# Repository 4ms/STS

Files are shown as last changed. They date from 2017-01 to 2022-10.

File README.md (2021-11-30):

# STS
## Stereo Triggered Sampler

Firmware for the Stereo Triggered Sampler, from 4ms Company.

The hardware contains:

*	180MHz 32-bit ARM chip with FPU (STM32F427)
*	Two Stereo codec chips, very low noise and low jitter (CS4721)
	*	Total of four audio inputs and four audio outputs
*	Eight potentiometers
*	Six Analogue inputs:
	*	Four unipolar analogue inputs (0 to 5V)
	*	Two bipolar analogue inputs (-5V to 5V)
*	Five LED buttons (momentary)
*	Two three-position switches
*	Five trigger/gate digital inputs
*	Three digital outputs
*	Two LEDs, capable of being dimmed with PWM
*	Separate analogue power supplies for each codec, and also the ADC 
*	Efficient 3.3V DC-DC converter accepts a wide range of input voltages

## Setting up your environment
You need to install the GCC ARM toolchain.
This project is known to compile with arm-none-eabi-gcc version 7.3.1, version 8.2.1, version 9.2.1, version 10.2.1, and 10.3.1. It's likely to compile with other versions as well.

It's recommended (but not necessary) to install ST-UTIL/stlink. Without it, you will have to update using the audio bootloader, which is very slow (5 minutes per update).
With ST-UTIL or stlink and a programmer, you can update in 5-20 seconds.
The Texane stlink package contains a gdb debugger, which works with ST-LINK programmers such as the [STM32 Discovery boards](http://www.mouser.com/ProductDetail/STMicroelectronics/STM32F4DISCOVERY/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) to connect to the Spectral's 4-pin SWD header. The STM32F4 Discovery Board is low-cost (under US$15) and works great as a programmer and debugger.

You also may wish to install an IDE such as Eclipse. There are many resources online for setting up GCC ARM with Eclipse (as well as commerical software). This is totally optional. Instead of an IDE you can use your favorite text editor and a few commands on the command line (Terminal) which are given below.

Continue below for Max OSX, Linux, or Windows instructions.

### Mac OSX

For Mac OSX, follow these instructions to install brew and then the arm toolchain and st-link (taken from https://github.com/nitsky/homebrew-stm32):

	ruby -e "$(curl -fsSL https://raw.githubusercontent.com/Homebrew/install/master/install)"
	brew tap nitsky/stm32
	brew install arm-none-eabi-gcc
	brew install stlink
	
Unfortunately `brew install arm-none-eabi-gcc` will download an old version of arm-none-eabi-gcc. This will work fine, so you can stop here if you want to do the easiest thing possible. But if you want to develop new firmware using C++17 or C++20 features, you'll need a newer toolchain. You can get a later version of arm-none-eabi-gcc [from ARM's website here](https://developer.arm.com/tools-and-software/open-source-software/developer-tools/gnu-toolchain/gnu-rm/downloads). After you unzip the download, add the `bin/` directory to your `PATH` like this:

	export PATH=$PATH:(path to the unzipped gcc-arm-none-eabi folder)/bin

Alternatively, if you don't want to mess with your PATH, you can export an environment variable that the Makefile will look for, like this (note the trailing slash):

	export TOOLCHAIN_DIR=(path to the unzipped gcc-arm-none-eabi folder)/bin/

That's it! Continue below to **Clone the Projects**

### Linux

For linux, check your package manager to see if there is a package for arm-none-eabi-gcc or gcc-arm-embedded or gcc-arm-none-eabi. Or just download it here:

[Download GCC ARM toolchain](https://developer.arm.com/tools-and-software/open-source-software/developer-tools/gnu-toolchain/gnu-rm/downloads)

Next, install st-link from texane:

	sudo apt-get install git libusb-1.0.0-dev pkg-config autotools-dev
	cd (your work directory)
	git clone https://github.com/texane/stlink.git
	cd stlink
	./autogen.sh
	./configure
	make
	export PATH=$PATH:(your work directory)/stlink

The last command makes sure that the binary st-flash is in your PATH so that the Makefile can run it to program your module. Alternatively you can omit the last command and run this instead:

	export TOOLCHAIN_DIR=(path to the unzipped gcc-arm-none-eabi folder)/bin/

The above environment variable will be used by the STS's Makefile to find the compiler.
 
That's it! Continue below to **Clone the Projects**

### Windows
[Download GCC ARM toolchain](https://developer.arm.com/tools-and-software/open-source-software/developer-tools/gnu-toolchain/gnu-rm/downloads)

[Download ST-UTIL](http://www.st.com/web/en/catalog/tools/PF258168)

Install both. Please contact me if you run into problems that you can't google your way out of! 

## Clone the Projects

Make sure git is installed on your system. (OSX: type `brew install git` into the Terminal)

Create a work directory, and enter it.

Clone this project (STS) and the required submodule (which is libhwtest)

	git clone https://github.com/4ms/STS.git
	cd STS
	git submodule update --init
	
If you don't need to change the bootloader firmware or generate a .wav file for updating firmware, then you can skip to **Compiling**.

Otherwise, if you want to modify the audio bootloader firmware, or create .wav files for sharing your custom firmware with others, then clone these projects as well:

	cd ..         ## if you were in the STS dir, go up one level
	git clone https://github.com/4ms/sts-bootloader.git  
	git clone https://github.com/4ms/stmlib.git
	git clone https://github.com/4ms/stm-audio-bootloader.git
	
Create a symlink for stm-audio-bootloader so that it works with python (required to generate the .wav file for audio bootloading)

     ln -s stm-audio-bootloader stm_audio_bootloader

Verify that your directories are as follows:

	(work directory)
	|  
	|--STS/  
	|--sts-bootloader/  
	|--stm-audio-bootloader/  
	|--stm_audio_bootloader/   <----symlink to stm-audio-bootloader
	|--stmlib/

## Compiling
Make your changes to the code in the STS directory. When ready to compile, build the project like this (make sure you're in the `STS/` directory)

	make

This creates an main.elf, main.bin, and main.hex file in the build/ directory.

## Programmer (Hardware) ##

Once you compile your firmware, you need to flash it to your STS. You will need a hardware device that connects to your computer's USB port. The other side of the programmer has a header that connects to the STS's 4-pin SWD header.

You have several options:

### Option 1) ST-LINKv2 programmer ###

The [ST-LINK v2 from ST corporation](http://www.mouser.com/search/ProductDetail.aspx?R=0virtualkey0virtualkeyST-LINK-V2) is the offical programmer from ST. The ST-LINK v2 has a 20-pin JTAG header, and you need to connect four of these to your STS. More details on this are below.

The ST-LINKv2 programmer can be used with ST-LINK software for Mac, Linux, or Windows; or ST-UTIL software for Windows; or STM32CubeProgrammer software for any platform. 

### Option 2) Discovery board programmer ###

The [STM32 Discovery boards](http://www.mouser.com/search/ProductDetail.aspx?R=0virtualkey0virtualkeySTM32F407G-DISC1) are low-cost (around US$25) and work great as a programmer and debugger. The 'Disco' board is essentially an ST-LINKv2, plus some extra stuff. While the ST-LINK v2 is encased in a plastic enclosure, the Discovery board is open and could potentially be damaged if you're not careful. Read the Discovery board's manual to learn about setting the jumpers to use it as an SWD programmer (rather than an evaluation board). ST makes many variations of the Discovery board, and to my knowledge they all contain an ST-LINK programmer.

The Discovery board programmer is essentially an ST-LINKv2, so it can be used with all the same software that the ST-LINKv2 can (see above section).

### Option 3) SEGGER's J-Link or J-Trace ###

Another option is [SEGGER's J-link programmer](https://www.segger.com/jlink-debug-probes.html). There is an educational version which is very affordable and a good choice for a programmer if you meet the requirements for educational use. There are various professional commercial versions with a number of useful features. The J-link uses SEGGER's propriety software, Ozone, which not only will flash a hex or bin file, but can be used as a powerful GUI debugger if you use it to open the .elf file. There also are command-line commands for flashing.
J-Link software runs on Mac, Linux, and Windows and is free of cost.

### Option 4) Audio Bootloader ###

The STS has an audio bootloader built-in, so you can just compile your project using `make wav` and then play the wav file into the audio input of the STS while in bootloader mode (see STS User Manual for detailed procedure). No additional hardware or software is necessary.

This works well and is the safest option. However it's very slow (up to 5 minutes per update). If you are going to be making a series of changes, this will be a very slow process! However if you want to share your custom firmware with others, it's a great way to package it since users don't need any special devices to update.

When ready to build an audio file for the bootloader, make it like this:

	make wav

This requires python to run. It creates the file `main.wav` in the `build/` directory. Play the file from a computer or device into the STS by following the instructions in the User Manual on the [4ms STS page](http://4mscompany.com/STS). 

## Programmer (Software)

Depending on the hardware you chose, one or more of the following software options will work:

### ST-LINK ###

This software works with the ST-LINK v2 and the Discovery board to flash your STS.

__MacOS:__

```
brew install stlink
```

__Linux:__

Use your package manager to install `stlink-tools`. See [stlink README](https://github.com/stlink-org/stlink) for direct links.

__Windows:__

Download the [latest binary (v1.3.0)](https://github.com/stlink-org/stlink/releases/download/v1.3.0/stlink-1.3.0-win64.zip). If that link doesn't work anymore, or you want to try a newer version, go to [stlink-org/stlink github page](https://github.com/stlink-org/stlink).

__Programming using st-link__

You can flash the compiled .bin file by typing either

	st-flash write build/main.bin 0x08008000

or the shortcut:

	make stflash
	
This writes the main.bin file starting at the 0x08008000 sector, which is the first sector of the application code.

__Debugging__

The gcc-arm toolchain includes a gdb debugger, but you'll need a server to use it. The st-link software includes st-util which will provide this. OpenOCD and J-link are two other options. Configuring debugging is beyond the scope of this README, but there are plenty of tutorials online. See the [stlink README](https://github.com/stlink-org/stlink) for a quick start.

### J-Link/Ozone ###

If you're using a J-Link or J-Trace hardware programmer to flash your STS, download and install [Ozone](https://www.segger.com/downloads/jlink). Ozone is a GUI debugger which can program, too. For command-line options, consider [J-Link Software and Documentation Pack](https://www.segger.com/j-link-software.html), which contains the GDB server and other tools.

To program your STS, open Ozone and then use the Project Wizard to create a new project. Select the STM32F427ZG for the chip. Use the default settings elsewhere. On the page that lets you select a file, select the main.elf file that you compiled. You can then save this project. To program, just click the green power/arrow symbol at the upper left.

You also can use the CLI tools to flash the hex/elf file, see J-Link documentation for details. The Makefile contains a shortcut for this:

	make flash

J-Link and Ozone is available for Mac, Windows, and Linux.

### STM32CubeProgrammer ###

The STM32CubeProgrammer is ST's official programaming software available for all platforms. [You can find it here](https://www.st.com/en/development-tools/stm32cubeprog.html)

Documentation is included with the download.

### ST-UTIL (Windows only) ###

ST-UTIL is a program from ST that runs on Windows only. You can find it on [ST.com](https://my.st.com/content/my_st_com/en/products/development-tools/software-development-tools/stm32-software-development-tools/stm32-programmers/stsw-link004.html)

It works with the ST-LINKv2 and Discovery boards.

## Connecting the programmer to the STS ##

**Discovery Board**: The Discovery board has a 6-pin SWD header, and you can connect that pin-for-pin to the first 4 pins on the STS's SWD header. You can use a 0.1" spaced 4-pin Jumper Wire such as [this one from Sparkfun](https://www.sparkfun.com/products/10364). Pay attention to Pin 1 (marked by "1" on the STS board), or you risk damaging the ARM chip.

**ST-LINK v2 or SEGGER J-Link**: Both the ST-LINK and the SEGGER J-link have a 20-pin JTAG connector. You need to connect 4 of these pins to the STS's 4-pin SWD connector, using 4 wires: [here's a pack of 10](https://www.sparkfun.com/products/8430). Pay attention to Pin 1 (marked by "1" on the STS board), or you risk damaging the ARM chip.
 
Look at these images:
 
  * JTAG: [20-pin pinout](http://www.jtagtest.com/pinouts/arm20)
  * SWD: [6-pin pinout](https://wiki.paparazziuav.org/wiki/File:Swd_header_discovery_board.png)
  * JTAG-to-SWD: [JTAG-to-SWD-pinout](https://4mscompany.com/JTAG-to-SWD-pinout.png). 

Then use your jumper wires to connect:
 
  * SWD pin 1 (VDD) -> JTAG pin 1 (VREF)
  * SWD pin 2 (SWCLK) -> JTAG pin 9 (TCK)
  * SWD pin 3 (GND) -> JTAG pin 4 (GND)
  * SWD pin 4 (SWDIO) -> JTAG pin 7 (TMS)

Here's more info in case you want it explained in another way:

  * [This image](https://www.alexwhittemore.com/wp-content/uploads/2014/08/schematic.jpg) draws this out. (Taken from [this post](https://www.alexwhittemore.com/st-linkv2-swd-jtag-adapter/))
  * [ST's manual](http://www.st.com/content/ccc/resource/technical/document/user_manual/70/fe/4a/3f/e7/e1/4f/7d/DM00039084.pdf/files/DM00039084.pdf/jcr:content/translations/en.DM00039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)
  * [How to make an adaptor](http://gnuarmeclipse.github.io/developer/j-link-stm32-boards/#the-st-6-pin-swd-connector)
  * Make your own adaptor from these gerber files: [JTAG-SWD-adaptor](https://github.com/4ms/pcb-JTAG-SWD-adaptor).

### Troubleshooting: ###

If you have trouble getting python to create a wav file, such as this error:

	ImportError: No module named stm_audio_bootloader

Then try this command:
	
	export PYTHONPATH=$PYTHONPATH:'.'

## Bootloader
The bootloader is a [separate project](https://github.com/4ms/stm-audio-bootloader), slightly modifed from the stm-audio-bootloader from [pichenettes](https://github.com/pichenettes/eurorack). 

The bootloader is already installed on all factory-built STS units.

## License
The code (software) is licensed by the MIT license.

The hardware is licensed by the [CC BY-NC-SA license](https://creativecommons.org/licenses/by-nc-sa/4.0/) (Creative Commons, Attribution, NonCommercial, ShareAlike).

See LICENSE file.

I would like to see others build and modify the STS and STS-influenced works, in a non-commercial manner. My intent is not to limit the educational use nor to prevent people buying hardware components/PCBs collectively in a group. If you have any questions regarding the license or appropriate use, please do not hesitate to contact me! 

## Guidelines for derivative works

Do not include the text "4ms" or "4ms Company" or the graphic 4ms logo on any derivative works. This includes faceplates, enclosures, or front-panels. It's OK (but not required) to include the text "Stereo Triggered Sampler" or "STS" if you wish.

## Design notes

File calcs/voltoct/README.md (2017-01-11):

Calculates volt/oct coefficients for Stereo Triggered Sampler
How to Use: Run ./mk
That's all. The output will be stored in voltoct.h, so move that to your project if you like.

If you want to see the output, run ./calc-voltoct

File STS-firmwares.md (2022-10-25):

# Stereo Triggered Sampler - Firmwares #
### How do I know what version I have? ###
Using a computer:

  * Put your microSD card into your computer. Open up the `__Sample List__.html` file. At the top it will say "Firmware version XXX".

Without a computer:

  1) Go into System Mode (_hold both Reverse, both Play, REC and REC Bank buttons down for a few seconds_). 

  2) Press and hold the Edit button. Look at the colors of Reverse buttons:

*  Left Reverse = __White__, Right Reverse = __Green__ ==> 1.5.x (latest version)
*  Left Reverse = __White__, Right Reverse = __Yellow__ ==> 1.4 
*  Left Reverse = __White__, Right Reverse = __Orange__ ==> 1.3
*  Left Reverse = __White__, Right Reverse = __Red__ ==> 1.2 
*  Left Reverse = __Orange__, Right Reverse = __Orange__ ==> 1.0 or 1.1 (see note below)

<!--
*Key: The left Reverse button shows the Major version number, and the right Reverse button shows the Minor version number. Off = 0, White = 1, Red = 2, Orange = 3, Yellow = 4, Green = 5, Cyan = 6, Blue = 7, Magenta = 8, Lavender = 9* -->

3) If the Reverse buttons stay Orange, then you have v1.0 or 1.1. To tell the difference between v1.0 and v1.1, press and hold just the left Reverse button in System Mode. If both Reverse buttons turn White, then you have v1.1. If they remain Orange, you have v1.0.

### Change log: ###

----
### v1.5.2b ###

*__Released:__* October 14, 2022

*__Download:__* [Firmware v1.5.2b](https://4mscompany.com/media/STS/firmware/STS-firmware-v1.5.2b.wav)

*__Improvements:__*

*__Bug Fixes:__*

   * __Start Pos would not go back to 0__: With longer sample files, adjusting Start Pos up and then back to 0 would sometimes set the start position such that the first few milliseconds of audio were truncated. Fixed.

   * __Clicking when re-triggering a sample with long Fade settings__: With longer Fade Up/Down Envelope times, re-triggering an already playing sample would prioritize low latency over the fade-down envelope, causing a click. In v1.5.2b the fade-down envelope is accelerated, adding a little bit of latency when re-triggering but removing the click. Setting the Fade Up/Down envelope time to fast removes the latency and clicking.

   * __Looping broken for very short samples when Perc Env is off__: When Percussive Envelope was turned off, setting the sample length to be very short could make it not loop. Bug introduced in 1.5.2. Fixed.

----
### v1.5.2 ###

*__Released:__* October 8, 2022

*__Improvements:__*

  * __Smaller firmware update files__: The size of the firmware file has been reduced, making the firmware update .wav file smaller by about 57% (from 5:55 to 3:22).

*__Bug Fixes:__*

   * __Long Fade In/Out Envelope times caused clicking in audio under certain circumstances__: When the Fade In/Out Envelope Time was set longer than the Trigger Delay Time, firing a play trigger into a channel that's already playing audio would cause the audio to re-start before the fade out had completed, causing a pop or click in the audio. Another circumstance was if the Fade In/Out Envelope Time or Percussive Envelope Time was set longer than time between Start Pos and the actual start of sample data, playing a sample in reverse would result in extra silence or glitchy audio. Bug appeared in v1.5, fixed in v1.5.2.

   * __Recording Sample Rate not presevered across reboots__: The Recording Sample Rate can be set in System Mode up to 96kHz. However, the next time the STS started up, the rate would be set back to 44.1kHz, yet the System Mode lights would indicate it was still in 96kHz. One symptom was that samples would play back at the wrong pitch. Bug fixed in v1.5.2.

----

### v1.5.1b ###

*__Released:__* June 28, 2022

*__New Features:__*

  * __Force Reload SD Card__: Hold down four buttons: Bank 1, Bank 2, Rec Bank and Rec, for about 2 seconds. Release the buttons when the startup sequence of lights displays.

*__Bug Fix:__*

   * __Unrelated sample file played in certain circumstances__: When Start Pos was high, within 0.5s of the end of the file, and Length was just under 50% (Percussive mode) but high enough such that a percussive burst longer than 0.5s was to be played, then the STS would overrun the sample data and play unrelated data (usually a previously played sample). Bug appeared in v1.5, fixed in v1.5.1b.
  
  (Note: v1.5.1a was not released)
  
----
### v1.5 ###

*__Released:__* June 6, 2022

*__Download:__* [Firmware v1.5](https://4mscompany.com/media/STS/firmware/STS-firmware-v1.5.zip)

*__New Features:__*

  * __Looping Fade Time__: The STS can make a longer crossfade between the end and start of a loop (adjustable from 0.36ms to 250ms). This results in a smoother, click-free loop.

  * __LED Color Adjustment__: You can now adjust the red, green, and blue amounts of each button, letting you match the colors between buttons. All new units ship pre-calibrated.

  * __Maximum Recording Rate__: You can now record up to 96kHz.

  * __Auto Increment Sample Slot on Record__: You can enable a mode that moves to the next sample slot each time you finish a recording that was started with the Rec Trigger jack.

  * __REC button flashes when you change sample slots__: The REC button flashes red or white when you turn the REC Sample knob to indicate if the slot is full or empty.

*__Bug Fix:__*

  * __PLAY button stayed dim red after a recording into an active slot__: Fixed. The PLAY button now indicates the selected sample slot is full immediately after recording into a previously empty slot.

  * __STS hangs on boot in some circumstances__: Fixed. An issue where the STS could hang on boot while searching for missing sample files is now fixed.

----
### v1.4g ###

*__Released:__* August 4, 2020

*__Download:__* [Firmware v1.4g](https://4mscompany.com/media/STS/firmware/STS-firmware-v1.4g.zip)

*__Bug Fix:__*

  * __Sequencing Start Pos Glitch Fixed__: Using a sequenced CV into Start Pos with gates/triggers into Play Trig would sometimes play the wrong start position if Length was < 50% and triggers were fired fast enough. Fixed.

----

Intermediate versions:

(1.4f released June 17, 2020. Improved performance of start-up sequence, and more types of "extended" wav file formats supported)

----

### v1.4e ###

*__Released:__* October 20, 2017

*__Download:__* (not available, please use v1.4g)

*__New Features:__*

  * __Reduced latency__ by pre-loading each sample file in a bank the first time each sample is played. 
     * Latency from trigger until audio output as low as 0.7ms (with Trigger Delay turned to 0, see below)
     * The first time a sample is played after the bank is changed, latency is typically 5ms (may be more depending on wav file's sampling rate and bit depth). Subsequent times the sample is triggered the latency is 0.7ms
  * __Variable "Trigger Delay"__: Edit + REC Sample knob 
    * Compensates for slew/lag when using a CV Sequencer with the Play Trig jack and the either the Sample CV or 1V/oct jack
    * This feature also allows for latency reduction compared to prior firmware versions, which had a built-in delay of about 14ms
    * After receiving a trigger on the Play jack, the STS will wait the specified delay period before reading the 1V/oct and Sample CV jacks.
    * To use: Press Edit and turn Rec Sample knob. The knob's numbers (1-10) correspond to a delay amount:
        * PCB v1.0a: ranges from 0ms delay (knob at 1) to 14.3ms delay (knob at 10) 
        * PCB v1.1: ranges from 0ms delay (knob at 1) to 1.9ms delay (knob at 8), and extra-long delays of 4.1ms (knob at 9) and 8.2ms (knob at 10)
    * _Note: If upgrading to v1.4 causes your sequencer and STS to not play well together, set the Trigger Delay to "8" or higher_ 

  * __Monitoring on/off per channel__: Left and right channels can monitor the inputs separately.
     * Pressing PLAY on one channel while monitoring is on will turn monitoring off for just that channel.
     * Only works in Mono mode.
     * Monitor LED blinks to indicate split monitoring.
     * _Typical use would be to patch Right OUT -> Left IN, then Left OUT -> mixer. Then record the right channel's playback._
    
  * __Start-up banks__: Can set the default bank to be loaded at start-up.
     * Hold down Edit + Bank 1 + Bank 2 + left PLAY (Save) for 1 second. Current bank selection will be saved as the default after power on. 
  * __Envelopes can be turned off__: Both percussive envelope and longer playback fade in/out envelope
     * Two types of envelopes can be turned on or off:
       * Percussive Envelopes: this is the decay-only envelope applied to playback when Length < 50% (actually an attack-only envelope when Reverse is on)
       * Fade In/Out envelope: this is a very short envelope applied to any sample that's played with Length > 50%. It reduces clicks when starting, stopping, or looping playback.
     * In System Mode, left channel Reverse button sets the envelope settings:
       * Orange: Both envelopes enabled (default)
       * Red: Percussive envelope disabled
       * Yellow: Fade In/Out envelopes disabled
       * Off: Both envelopes disabled
     * Turning off all envelopes is recommended when playing CV sample files (wav files with clocks/gates, sequencer CV, or slow LFO waveshapes, etc).
     * Turning off Percussive Envelopes is interesting when doing "Granular" patches (see User Manual for example patches)
     * Can toggle Percussive Envelope mode by turning left side Length to 0, and holding left side Reverse for 2 seconds: Reverse button will flash/flicker
     * Can toggle Fade In/Out Envelope mode by turning left side Length to 100%, and holding left side Reverse for 2 seconds: Reverse button will flash/flicker
     
*__Fixes:__*

  * After exiting System Mode, right side Length was set to 0, until the knob was moved. Fixed.

----
Intermediate versions: (1.4beta-1 released October 13, 2017)
(1.4beta-2 released October 17, 2017: changed Length behavior)
(1.4c fixed sticky right length knob when exiting system mode)
(1.4d fixed bugs that appeared in v1.4beta2) 
(1.4e fixed bugs that appeared in v1.3) 
(1.4f more filtering on 1V/oct jacks, and quantized mode plays better with tracking comp setting) 

----
#### v1.3

*Released:* (beta released Sept 26, 2017)

*Download:* [Firmware v1.3 WAV file](http://4mscompany.com/media/STS/firmware/STS-firmware-v1.3.zip)

*New Features:*
 
  * __Drag-and-dropping WAV files to SD card works better__:
    * Adding WAV files to an existing folder now adds the files to the bank if there are empty slots.
    * If there are no empty slots, the files can be added using Edit + Next File.
    * On boot, the STS will try to fill empty slots in banks by searching in the bank's folder:
      * If the bank contains files from multiple folders, the lowest-numbered sample file's folder is used. 

  * __Adjust 1V/OCT jack offset__
    * Hold down Bank 1 + Bank 2 + Edit while tapping either REC or REC Bank button.
      * REC shifts downwards, REC Bank shifts upwards.
    * Settings are saved in memory (save using Edit + Save after making necessary adjustments).
    * If there is a difference in pitch between the audio being monitored and playback, or a difference in playback pitch between channels, then this may need to be adjusted. All units are calibrated in the factory, but variations in power supplies and grounding configurations of cases may cause DC offset to appear in a user's system.
    
*Fixes:*

  * Creating a folder with an exact color name in all lowercase added the folder twice. Fixed.
  * Edit+Next File while in an empty slot now searches in the folder of the first filled slot.

----
#### v1.2

*Released:* (released Sept 8, 2017)

*Download:* [Firmware v1.2 WAV file](http://4mscompany.com/media/STS/firmware/STS-firmware-v1.2.zip)

*New Features:*

  * __Quantize 1V/oct jack__ added to System Mode. Each channel can be on/off seperately. Quantization is to semitones (12 notes per octave).
    * In System Mode, tap Bank button for either channel to toggle state.
    * Blue = On (jack is quantized to semitones)
    * Orange = Off (jack is not quantized)
    * Only effects 1V/oct jack, not the Pitch knob
    * Setting is saved in settings file on microSD card
    
  * __Reset tracking compensaion__ to 1.0000
    * Holding Edit+Rec+RecBank  
    * Updating from v1.0 or v1.1 to v1.2 or later automatically sets tracking to 1.0000 the first time it is loaded (this is necessary because tracking is calculated differently in v1.2 and later)

  * __Auto Stop When Sample Changes__:  "Always keep playing" mode added. There are now three Auto Stop modes. The modes determine what happens when the sample is changed while a sample is being played.
    * Red = Always Stop: The sample instantly stops playing. If looping is on, the new sample starts playing immediately.
    * Blue = Change When Looping:  The sample keeps playing normally -- unless it's looping, in which case it stops immediately and the new sample starts.
    * Green = Always Keep Playing: The sample keeps playing normally. If it's looping then the new sample begins when the previous sample reaches the end.

*Fixes:*

  * 1V/octave tracking is tighter, +/-0.4 cents over C0-C3
 
*Changes:*

  * Faster entry into System Mode (2 seconds, instead of 4)
  * Pitch knob's plateau around the center detent is larger, and gradually slopes away from center to make it easier to tune to other sources

----
#### v1.1

*Released:* August 28, 2017

*Download:* [Firmware v1.1 WAV file](http://4mscompany.com/media/STS/firmware/STS-firmware-v1.1.zip)

*Changes:*

  * On boot, color of lights while index file is loading shows minor version number
  * In System Mode, holding down Reverse displays firmware version on Reverse buttons (White, White = 1.1)
  
*Fixes:*

  * Tapping Reverse after changing Channel Volume prematurely updated the Start Pos setting. Fixed.
  * Scrub End setting for samples was not loaded after reboot until Edit button was pushed. Fixed.

----
#### v1.0

Released: August 10, 2017

*Initial Release*

----

#### Features for future firmware versions:
  * Allow for internally patching OUTs to INs for self-recording
  * Support AIFF files
  * Write index file in background, for faster boot time and "Edit+Save" time

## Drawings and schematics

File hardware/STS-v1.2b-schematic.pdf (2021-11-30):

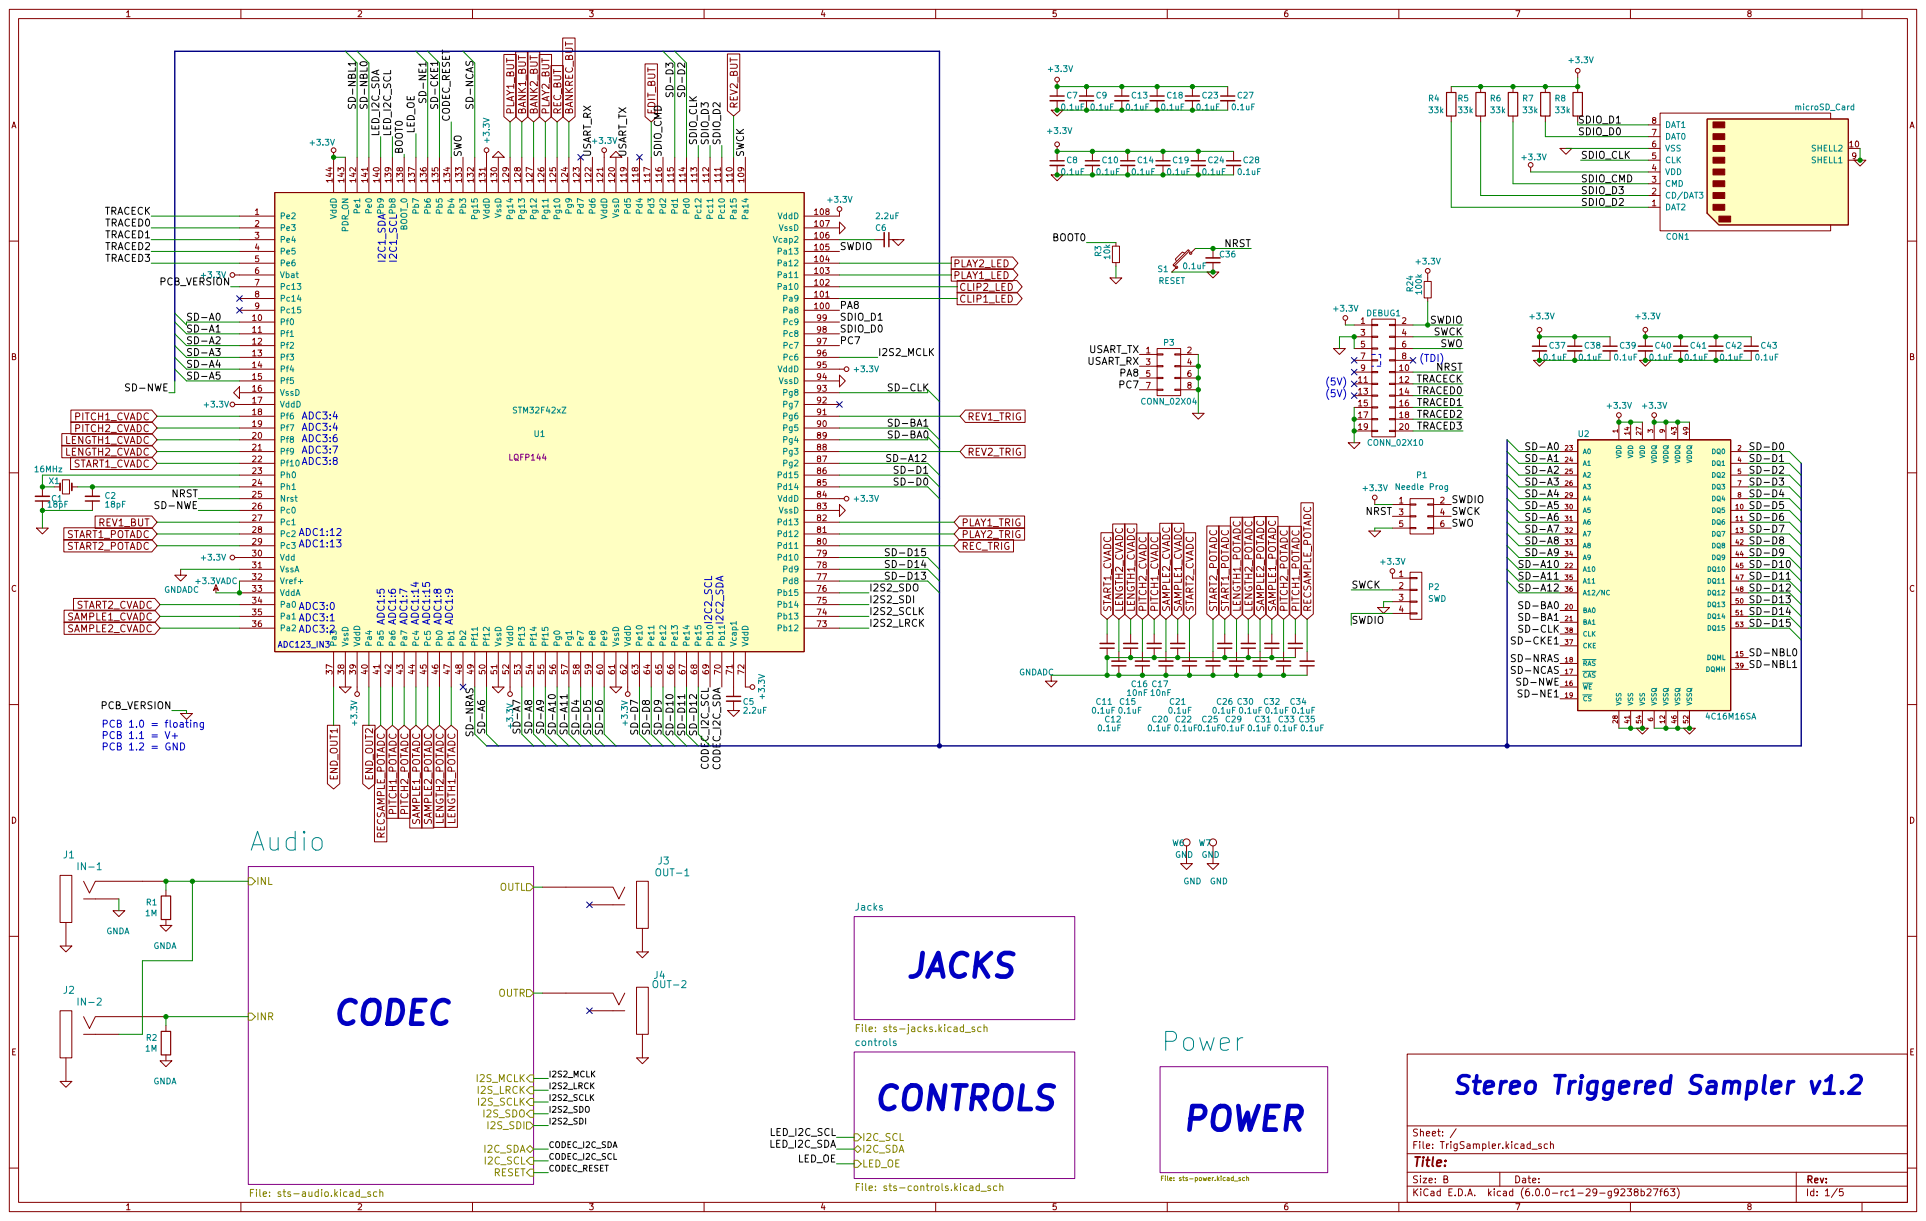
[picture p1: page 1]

3 A5 30 A6 31 A7 32 A8 33 A9 34 A11 35 A12/NC 36 CKE 37 CLK 38 DQMH

File: TrigSampler.kicad_sch Sheet: / OUTL

Jacks File: sts-jacks.kicad_sch
JACKS

controls File: sts-controls.kicad_sch
POWER CONTROLS

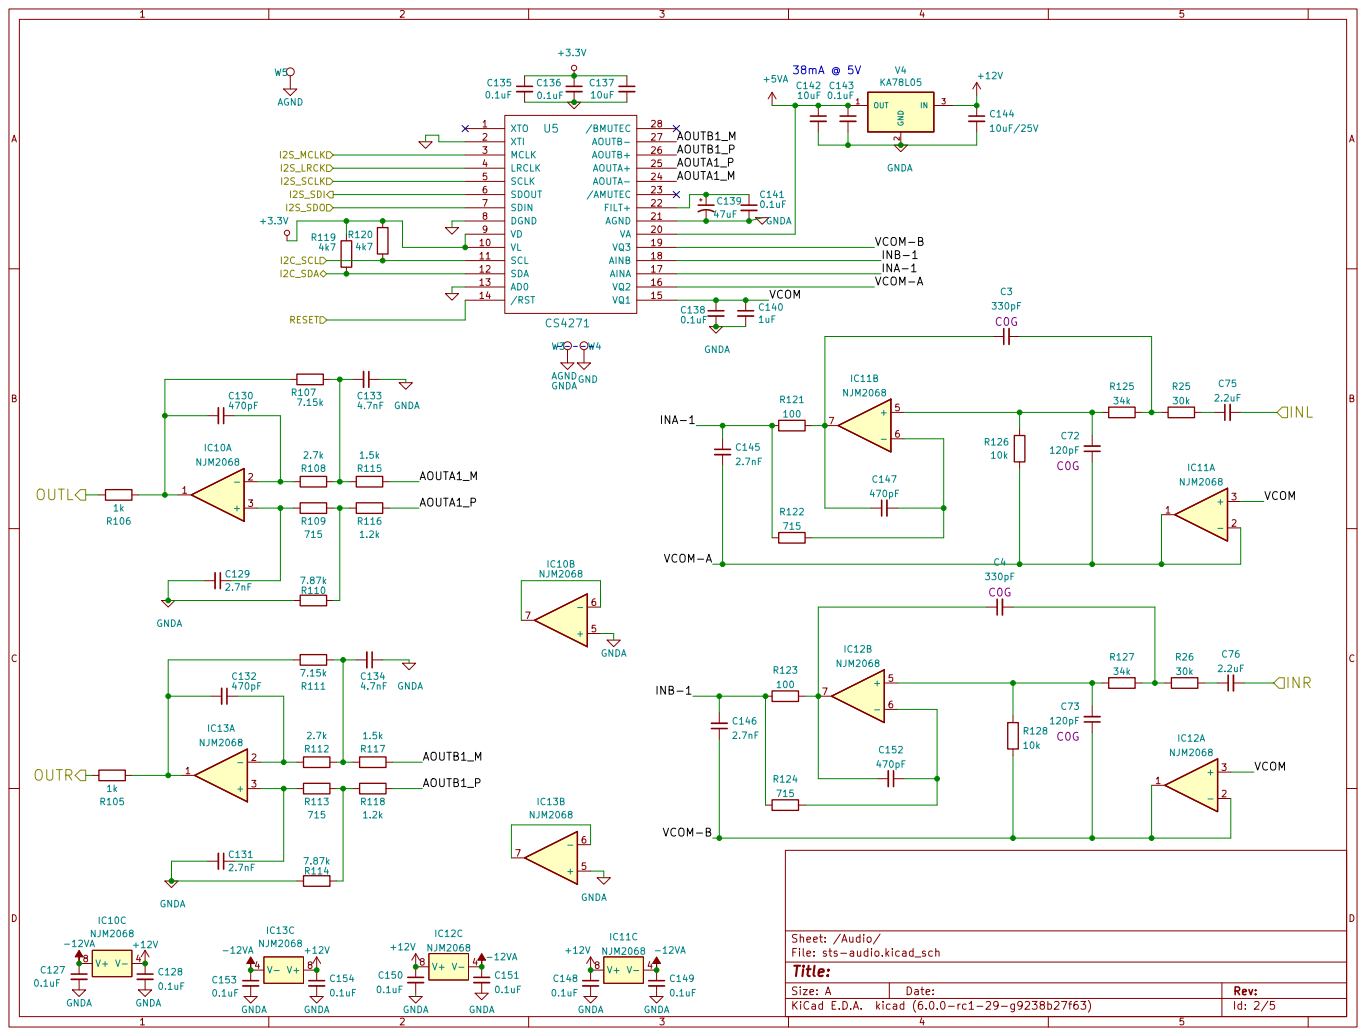
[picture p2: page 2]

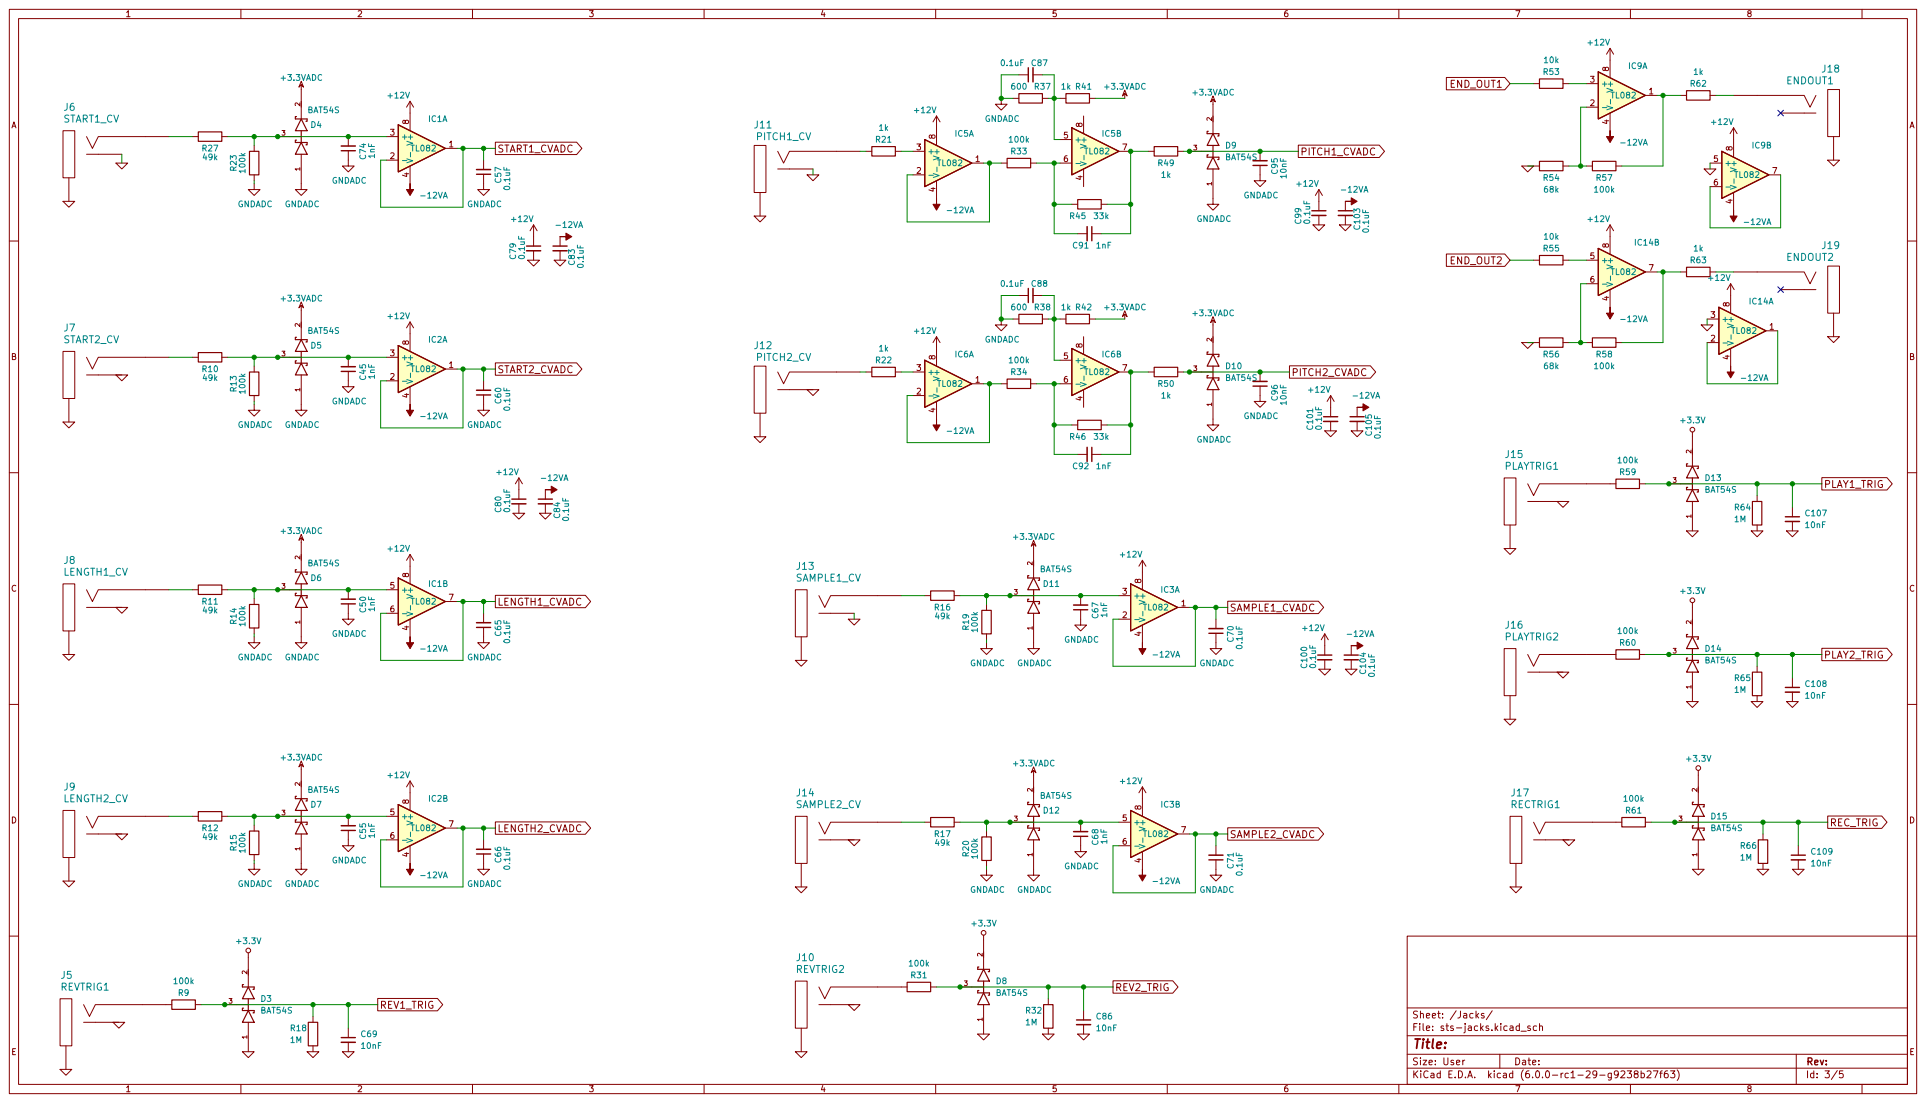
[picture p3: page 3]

File: sts-jacks.kicad_sch Sheet: /Jacks/

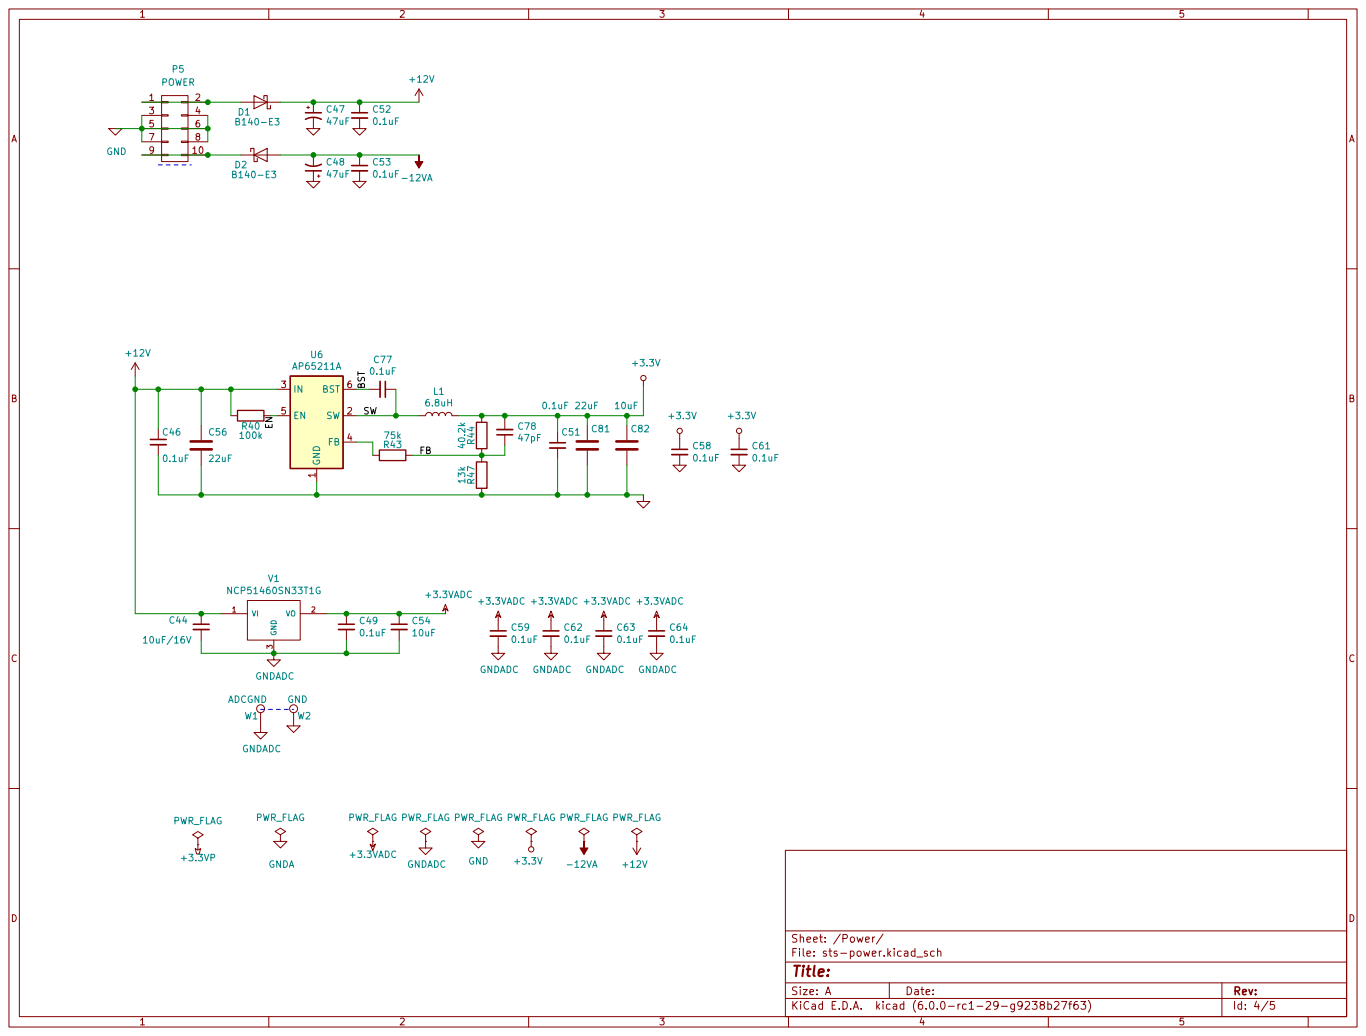
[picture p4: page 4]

FB BST SW EN

File: sts-power.kicad_sch Sheet: /Power/

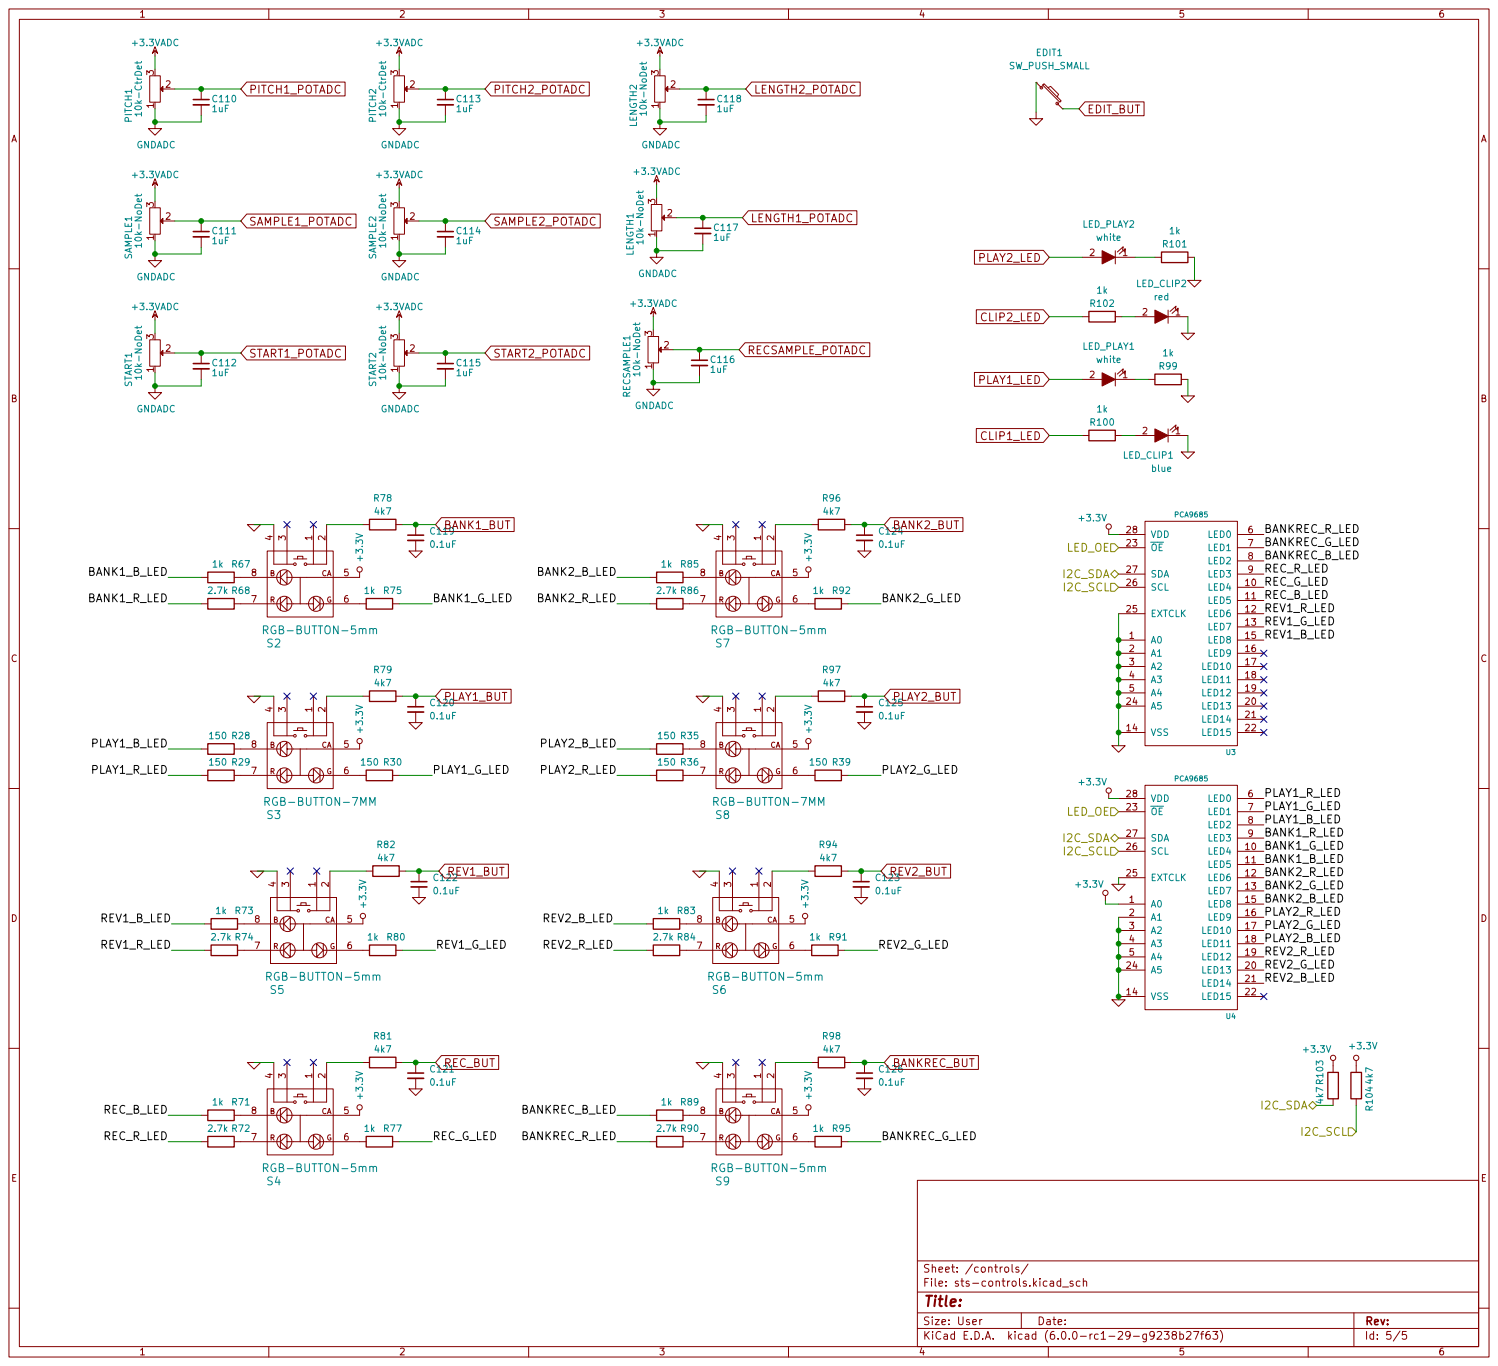
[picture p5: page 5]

File: sts-controls.kicad_sch Sheet: /controls/

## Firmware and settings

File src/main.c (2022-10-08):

/*
 * main.c - Stereo Triggered Sampler
 *
 * Author: Dan Green (danngreen1@gmail.com)
 *
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
 * See http://creativecommons.org/licenses/MIT/ for more information.
 *
 * -----------------------------------------------------------------------------
 */

#include "globals.h"
#include <stm32f4xx.h>

#include "sampler.h"
#include "sdram_driver.h"

#include "ITM.h"
#include "adc.h"
#include "audio_codec.h"
#include "audio_sdram.h"
#include "bank.h"
#include "buttons.h"
#include "calibration.h"
#include "codec.h"
#include "dig_pins.h"
#include "edit_mode.h"
#include "fatfs_util.h"
#include "ff.h"
#include "hardware_tests.h"
#include "i2s.h"
#include "led_color_adjust.h"
#include "leds.h"
#include "params.h"
#include "pca9685_driver.h"
#include "rgb_leds.h"
#include "sampler.h"
#include "stm32f4_discovery_sdio_sd.h"
#include "sts_filesystem.h"
#include "sts_sampleindex.h"
#include "system_mode.h"
#include "timekeeper.h"
#include "user_flash_settings.h"
#include "user_settings.h"
#include "wav_recording.h"

#define HAS_BOOTLOADER

// These must match what's in startup_stm32f4xx.s:
#define BOOTLOADER_MAGIC_CODE 0xBADDCAFE
#define BOOTLOADER_MAGIC_ADDRESS *((uint32_t *)(0x2001FFF0))

uint8_t PCB_version = 0;

FATFS FatFs;

enum g_Errors g_error = 0;

extern uint8_t global_mode[NUM_GLOBAL_MODES];
extern GlobalParams global_params;

extern uint8_t flags[NUM_FLAGS];
extern uint32_t flags32[NUM_FLAGS];

extern SystemCalibrations *system_calibrations;

void check_errors(void);
void check_errors(void) {
	if (g_error > 0) {
	}
}

uint8_t check_bootloader_keys(void) {
	uint32_t dly;
	uint32_t button_debounce = 0;

	dly = 32000;
	while (dly--) {
		if (BOOTLOADER_BUTTONS)
			button_debounce++;
		else
			button_debounce = 0;
	}
	return (button_debounce > 15000);
}

void deinit_all(void);
void deinit_all(void) {
	f_mount(0, "", 0);
	SD_DeInit();
	Deinit_CV_ADC();
	Deinit_Pot_ADC();
	codec_resetpin_low();
	stop_audio_clock_source();
	deinit_audio_dma();
	deinit_dig_inouts();
}

static unsigned is_preproduction_firmware(unsigned v_major, unsigned v_minor);

void main(void) {
	uint32_t do_factory_reset = 0;
	uint32_t timeout_boot;
	uint32_t valid_fw_version;
	FRESULT res;

	SD_DeInit();

	LEDDRIVER_OUTPUTENABLE_OFF;

#ifndef HAS_BOOTLOADER
	NVIC_SetVectorTable(NVIC_VectTab_FLASH, 0x0000);
#endif

#ifdef DEBUG_ENABLED
	TRACE_init();
#endif

	//Codec and I2S/DMA should be disabled before they can properly start up
	codec_resetpin_low();
	stop_audio_clock_source();
	deinit_audio_dma();
	delay();

#ifdef HAS_BOOTLOADER
	if (check_bootloader_keys()) {
		BOOTLOADER_MAGIC_ADDRESS = BOOTLOADER_MAGIC_CODE;
		NVIC_SystemReset();
	}
	NVIC_SetVectorTable(NVIC_VectTab_FLASH, 0x8000);
#endif

	init_dig_inouts();

	PCB_version = get_PCB_version();

	if (PCB_version == 0xFF) {
		// invalid version: display error code: all LEDs on for a second
		timeout_boot = 0x08000000;
		PLAYLED1_ON;
		PLAYLED2_ON;
		SIGNALLED_ON;
		BUSYLED_ON;
		while (timeout_boot--) {
			;
		}
		PLAYLED1_OFF;
		PLAYLED2_OFF;
		SIGNALLED_OFF;
		BUSYLED_OFF;
	}

	// Turn on middle lights, for debugging
	SIGNALLED_ON;
	BUSYLED_ON;

	init_timekeeper();

	SDRAM_Init();

	if (HARDWARETEST_BUTTONS)
		do_hardware_test();

	delay();

	timeout_boot = 0x00800000;
	PLAYLED1_ON;
	while (timeout_boot--) {
		;
	}
	PLAYLED1_OFF;

	// Turn off middle lights, for debugging
	SIGNALLED_OFF;
	BUSYLED_OFF;

	reload_sdcard();

	// Turn on the lights
	LEDDriver_Init(2); // 2 = # of LED driver chips
	all_buttonLEDs_off();

	global_mode[CALIBRATE] = 0;

	valid_fw_version = load_flash_params();

	// Check for calibration buttons on boot
	if (ENTER_CALIBRATE_BUTTONS) {
		flags[SkipProcessButtons] = 1;
		global_mode[CALIBRATE] = 1;
	} else if (VIDEO_DIM_BUTTONS) {
		global_mode[VIDEO_DIM] = 7;
		system_calibrations->led_brightness = 1;
	}
	// First boot: Run a hardware test, calibrate, and do a factory reset
	else if (!valid_fw_version || is_preproduction_firmware(system_calibrations->major_firmware_version,
															system_calibrations->minor_firmware_version))
	{
		set_default_led_color_adjust();
		LEDDRIVER_OUTPUTENABLE_ON;

		if (do_hardware_test()) {
			global_mode[CALIBRATE] = 1;
			do_factory_reset = 960000; // run normally for about 6 seconds before
									   // calibrating the CV jacks
		} else {
			while (1)
				; // halt
		}
	}

	if (TEST_LED_BUTTONS)
		test_all_buttonLEDs();

	init_buttonLEDs();
	init_ButtonLED_IRQ();
	init_LED_PWM_IRQ();

	// Initialize ADCs
	Deinit_Pot_ADC();
	Deinit_CV_ADC();
	init_LowPassCoefs();
	Init_Pot_ADC();
	Init_CV_ADC();

	// Initialize parameters/modes
	init_adc_param_update_IRQ();

	set_default_user_settings();
	read_user_settings();
	init_params();
	init_modes();

	//Initialize Codec
	codec_init_gpio();
	codec_init_i2s(global_params.record_sample_rate);
	init_audio_dma();
	codec_setup_registers(0, global_params.record_sample_rate);

	// If we detect a different version, update the firmware version in FLASH
	if (system_calibrations->major_firmware_version != FW_MAJOR_VERSION ||
		system_calibrations->minor_firmware_version != FW_MINOR_VERSION)
	{
		LEDDRIVER_OUTPUTENABLE_ON;

		apply_firmware_specific_adjustments();
		copy_system_calibrations_into_staging();
		set_firmware_version();
		write_all_system_calibrations_to_FLASH();
	}

	flags[SystemModeButtonsDown] = 0;

	// Begin reading inputs
	init_buttons();
	init_ButtonDebounce_IRQ();
	init_TrigJackDebounce_IRQ();

	// Begin audio DMA
	audio_buffer_init();

	// request unaltered backup of index @ boot
	flags[BootBak] = 1;

	// Turn on button LEDs for bank loading
	LEDDRIVER_OUTPUTENABLE_ON;

	// Load all banks
	init_banks(); // calls load_all_banks which calls index_write_wrapper()

	// Backup index file (unless we are booting for the first time)
	if (!do_factory_reset)
		backup_sampleindex_file();

	set_codec_callback(process_audio_block_codec);
	start_audio_stream();

	delay();

	init_SDIO_read_IRQ();

	// Main loop
	// All routines accessing the SD card should run here
	while (1) {

		check_errors();

		write_buffer_to_storage();

		if (flags[TimeToReadStorage]) {
			flags[TimeToReadStorage] = 0;
			read_storage_to_buffer();
		}

		if (flags[FindNextSampleToAssign]) {
			do_assignment(flags[FindNextSampleToAssign]);
			flags[FindNextSampleToAssign] = 0;
		}

		if (flags32[SaveUserSettingsLater]) {
			flags32[SaveUserSettingsLater]--;

			if (flags32[SaveUserSettingsLater] == 0)
				flags[SaveUserSettings] = 1;
		}

		if (flags[SaveUserSettings]) {
			flags[SaveUserSettings] = 0;
			save_user_settings();
		}

		process_mode_flags();

		if (flags[RewriteIndex]) {
			res = index_write_wrapper();
			if (res) {
				flags[RewriteIndexFail] = 255;
				g_error |= CANNOT_WRITE_INDEX;
			} else
				flags[RewriteIndexSucess] = 255;

			flags[RewriteIndex] = 0;
		}

		if (flags[LoadIndex]) {
			load_all_banks(0);
			// load_sampleindex_file(USE_INDEX_FILE, ALL_BANKS);
			flags[LoadIndex] = 0;
			flags[ForceFileReload1] = 1;
			flags[ForceFileReload2] = 1;
		}

		if (flags[LoadBackupIndex]) {
			load_sampleindex_file(USE_BACKUP_FILE, flags[LoadBackupIndex] - 1);
			flags[LoadBackupIndex] = 0;
			flags[ForceFileReload1] = 1;
			flags[ForceFileReload2] = 1;
		}

		if (flags[ShutdownAndBootload]) {
			flags[ShutdownAndBootload] = 0;
			deinit_all();

			BOOTLOADER_MAGIC_ADDRESS = BOOTLOADER_MAGIC_CODE;
			NVIC_SystemReset();
		}

		if (do_factory_reset)
			if (!(--do_factory_reset))
				factory_reset();
	}
}

static unsigned is_preproduction_firmware(unsigned v_major, unsigned v_minor) {
	//Minimum firmware version that doesn't need a calibration on the very first boot
	const unsigned FORCE_CAL_UNDER_FW_MAJOR_VERSION = 0;
	const unsigned FORCE_CAL_UNDER_FW_MINOR_VERSION = 2;

	if ((v_major < FORCE_CAL_UNDER_FW_MAJOR_VERSION) ||
		((v_major == FORCE_CAL_UNDER_FW_MAJOR_VERSION) && v_minor < FORCE_CAL_UNDER_FW_MINOR_VERSION))
		return 1;
	return 0;
}

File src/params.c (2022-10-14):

/*
 * params.c - Reads UI elements, conditions signals and sets parameter values
 *
 * Author: Dan Green (danngreen1@gmail.com)
 *
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
 * See http://creativecommons.org/licenses/MIT/ for more information.
 *
 * -----------------------------------------------------------------------------
 */

#include "params.h"
#include "adc.h"
#include "bank.h"
#include "button_knob_combo.h"
#include "buttons.h"
#include "calibration.h"
#include "dig_pins.h"
#include "edit_mode.h"
#include "equal_pow_pan_padded.h"
#include "globals.h"
#include "led_color_adjust.h"
#include "log_taper_padded.h"
#include "pitch_pot_lut.h"
#include "rgb_leds.h"
#include "sampler.h"
#include "system_mode.h"
#include "voltoct.h"
#include "wav_recording.h"

#define MAX_FIR_LPF_SIZE 80
uint32_t FIR_LPF_SIZE[NUM_CV_ADCS];

extern uint8_t PCB_version;

//CV LPFs
CCMDATA int32_t fir_lpf[NUM_CV_ADCS][MAX_FIR_LPF_SIZE];
uint32_t fir_lpf_i[NUM_CV_ADCS];

extern const float pitch_pot_lut[4096];
extern const float voltoct[4096];

extern enum PlayStates play_state[NUM_PLAY_CHAN];

extern __IO uint16_t potadc_buffer[NUM_POT_ADCS];
extern __IO uint16_t cvadc_buffer[NUM_CV_ADCS];

extern SystemCalibrations *system_calibrations;

extern Sample samples[MAX_NUM_BANKS][NUM_SAMPLES_PER_BANK];

extern uint8_t disable_mode_changes;

volatile float f_param[NUM_PLAY_CHAN][NUM_F_PARAMS];
uint8_t i_param[NUM_ALL_CHAN][NUM_I_PARAMS];
uint8_t settings[NUM_ALL_CHAN][NUM_CHAN_SETTINGS];
uint8_t global_mode[NUM_GLOBAL_MODES];
GlobalParams global_params;

uint8_t flags[NUM_FLAGS]; //FixMe: is it OK to use 32-bit flags?
uint32_t flags32[NUM_FLAGS];

uint32_t play_trig_timestamp[2];

uint8_t pot_changed[NUM_POT_ADCS];

extern uint8_t recording_enabled;

extern enum ButtonStates button_state[NUM_BUTTONS];
extern uint8_t button_ignore[NUM_BUTTONS];

volatile uint32_t sys_tmr;

extern ButtonKnobCombo g_button_knob_combo[NUM_BUTTON_KNOB_COMBO_BUTTONS][NUM_BUTTON_KNOB_COMBO_KNOBS];

//jack/pot LPF coefficients:
float POT_LPF_COEF[NUM_POT_ADCS];
float RAWCV_LPF_COEF[NUM_CV_ADCS];

//jack/pot LPF bracketing amounts:
int32_t POT_BRACKET[NUM_POT_ADCS];
int32_t CV_BRACKET[NUM_CV_ADCS];

// Latched 1voct values
uint32_t voct_latch_value[2];

//Low Pass filtered adc values:
float smoothed_potadc[NUM_POT_ADCS];
float smoothed_cvadc[NUM_CV_ADCS];

//Integer-ized LowPassFiltered adc values:
int16_t i_smoothed_potadc[NUM_POT_ADCS];
int16_t i_smoothed_cvadc[NUM_CV_ADCS];

//LPF -> Bracketed adc values
int16_t bracketed_cvadc[NUM_CV_ADCS];
int16_t bracketed_potadc[NUM_POT_ADCS];

//Latched pot value for use during edit mode
extern int16_t editmode_latched_potadc[NUM_POT_ADCS];

//LPF of raw ADC values for calibration
int16_t i_smoothed_rawcvadc[NUM_CV_ADCS];

//Change in pot since last process_adc
int32_t pot_delta[NUM_POT_ADCS];
int32_t cv_delta[NUM_CV_ADCS];

void init_params(void) {
	uint32_t chan, i;

	for (chan = 0; chan < NUM_PLAY_CHAN; chan++) {
		f_param[chan][PITCH] = 1.0;
		f_param[chan][START] = 0.0;
		f_param[chan][LENGTH] = 1.0;
		f_param[chan][VOLUME] = 1.0;

		i_param[chan][BANK] = 0;
		i_param[chan][SAMPLE] = 0;
		i_param[chan][REV] = 0;
		i_param[chan][LOOPING] = 0;
	}

	i_param[REC][BANK] = 0;
	i_param[REC][SAMPLE] = 0;

	for (i = 0; i < NUM_FLAGS; i++) {
		flags[i] = 0;
	}

#ifdef ENABLE_VARIABLE_RECORD_SAMPLE_RATE
	if (global_params.record_sample_rate < REC_44K || global_params.record_sample_rate > REC_96K)
		global_params.record_sample_rate = REC_44K;
	global_params.f_record_sample_rate = (float)(global_params.record_sample_rate);
#else
	global_params.record_sample_rate = REC_44K;
	global_params.f_record_sample_rate = 44100.f;
#endif

	global_params.play_trig_delay = calc_trig_delay(global_mode[TRIG_DELAY]);
	global_params.play_trig_latch_pitch_time = calc_pitch_latch_time(global_mode[TRIG_DELAY]);

	if (global_params.fade_time_ms > 255)
		global_params.fade_time_ms = 6;
	global_params.fade_down_rate = calc_fade_updown_rate(global_params.fade_time_ms);
	global_params.fade_up_rate = calc_fade_updown_rate(global_params.fade_time_ms);

	if (global_params.auto_inc_slot_num_after_rec_trig > 1)
		global_params.auto_inc_slot_num_after_rec_trig = 0;
}

//initializes modes that aren't read from flash ram or disk
void init_modes(void) {
	//global_mode[CALIBRATE] = 0;
	global_mode[SYSTEM_MODE] = 0;
	global_mode[MONITOR_RECORDING] = MONITOR_OFF;
	global_mode[ENABLE_RECORDING] = 0;
	global_mode[EDIT_MODE] = 0;
	global_mode[ASSIGN_MODE] = 0;

	global_mode[ALLOW_SPLIT_MONITORING] = 1;
	global_mode[VIDEO_DIM] = 0;
}
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

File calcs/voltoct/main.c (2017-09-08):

#include <stdio.h>
#include <stdarg.h>
#include <stdlib.h>
#include <string.h>
#include <sys/malloc.h>
#include <errno.h>
#include <ctype.h>
#include <sys/types.h>
#include <sys/stat.h>
#include <fcntl.h>
#include <time.h>
#include <math.h>


#ifdef T_MSVC
#include <float.h>
#define NAN nan_global
#endif

#include <sys/ioctl.h>
#include <sys/times.h>

#define ADCVALS_PER_OCTAVE 408.0
#define CENTER_ADC 2048
int main(void){
	int i;
	double v;
	double pitch_per_adcval;

	pitch_per_adcval = pow(2.0, 1.0/ADCVALS_PER_OCTAVE);

	printf ("const float voltoct[4096]={\n");

	for (i=0;i<4096;i++)
	{
		v = pow(pitch_per_adcval, (CENTER_ADC - i));

		printf("%.16g",v);
		if (i!=4095) 	printf(",");
		printf("\t//%d\n",i);
	}
	printf ("};\n");

	return(0);
}

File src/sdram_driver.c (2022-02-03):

//=================================================================================================
// STM32F429I-Discovery SDRAM configuration
// Author : Radoslaw Kwiecien
// e-mail : radek@dxp.pl
// http://en.radzio.dxp.pl/stm32f429idiscovery/
// Date : 24.11.2013
//=================================================================================================
#include "sdram_driver.h"
#include "dig_pins.h"
#include "globals.h"
#include "gpiof4.h"
#include "leds.h"

//=================================================================================================
// Macros for SDRAM Timing Register
//=================================================================================================
#define TMRD(x) (x << 0)
#define TXSR(x) (x << 4)
#define TRAS(x) (x << 8)
#define TRC(x) (x << 12)
#define TWR(x) (x << 16)
#define TRP(x) (x << 20)
#define TRCD(x) (x << 24)
//=================================================================================================
// GPIO configuration data
//=================================================================================================
static GPIO_TypeDef *const GPIOInitTable[] = {GPIOF, GPIOF, GPIOF, GPIOF, GPIOF, GPIOF, GPIOF, GPIOF, GPIOF, GPIOF,
											  GPIOG, GPIOG, GPIOG, GPIOD, GPIOD, GPIOD, GPIOD, GPIOE, GPIOE, GPIOE,
											  GPIOE, GPIOE, GPIOE, GPIOE, GPIOE, GPIOE, GPIOD, GPIOD, GPIOD, GPIOB,
											  GPIOB, GPIOC, GPIOE, GPIOE, GPIOF, GPIOG, GPIOG, GPIOG, GPIOG, 0};
static uint8_t const PINInitTable[] = {
	/* F */ 0,	1,	2,	3,	4,	5,	12, 13, 14, 15,
	/* G */ 0,	1,	2,
	/* D */ 14, 15, 0,	1,
	/* E */ 7,	8,	9,	10, 11, 12, 13, 14, 15,
	/* D */ 8,	9,	10,
	/* B */ 5,	6,
	/* C */ 0,
	/* E */ 0,	1,
	/* F */ 11,
	/* G */ 4,	5,	8,	15, 0};
//=================================================================================================
// SDRAM_Init function
//=================================================================================================
void SDRAM_Init(void) {
	//volatile uint32_t ptr = 0;
	volatile uint32_t i = 0;

	RCC->AHB1ENR |= RCC_AHB1ENR_GPIODEN | RCC_AHB1ENR_GPIOEEN | RCC_AHB1ENR_GPIOFEN | RCC_AHB1ENR_GPIOGEN;

	while (GPIOInitTable[i] != 0) {
		gpio_conf(GPIOInitTable[i], PINInitTable[i], MODE_AF, TYPE_PUSHPULL, SPEED_100MHz, PULLUP_NONE, 12);
		i++;
	}

	RCC->AHB3ENR |= RCC_AHB3ENR_FMCEN;

	// Initialization step 1

	//SDCLK period = 2 x HCLK periods
	//RBURST: single read requests are always managed as bursts
	//RPIPE: (delay, in HCLK clock cycles, for reading data after CAS latency) = Two HCLK clock cycle delay
	FMC_Bank5_6->SDCR[0] = FMC_SDCR1_SDCLK_1 | FMC_SDCR1_RBURST | FMC_SDCR1_RPIPE_1;
	//FMC_Bank5_6->SDCR[0] = FMC_SDCR1_SDCLK_1   | FMC_SDCR1_RPIPE_1;

	//64Mbit (8MByte):
	//NR_0: Num Rows=12
	//NC (not present): Num Columns=8
	//MWID_0: Memory width=16 bits
	//NB: Num Banks=4
	//CAS: CAS latency=3 cycles
	//FMC_Bank5_6->SDCR[1] = FMC_SDCR1_NR_0	  | FMC_SDCR1_MWID_0 | FMC_SDCR1_NB | FMC_SDCR1_CAS;

	//256Mbit (32MByte):
	//NR_1: Num Rows=13
	//NC_0: Num Columns=9
	//MWID_1: Memory width=16
	//NB: Num Banks=4
	//CAS: CAS latency=3 cycles
	FMC_Bank5_6->SDCR[1] = FMC_SDCR1_NR_1 | FMC_SDCR1_NC_0 | FMC_SDCR1_MWID_0 | FMC_SDCR1_NB | FMC_SDCR1_CAS;

	// Initialization step 2
	// Timing characteristics, expressed in number of clock cycles (@180MHz, SDCLK is HCLK/2 means a value of 1 = 11.1ns, 2 = 22.2ns etc..)
	FMC_Bank5_6->SDTR[0] = TRC(6) | TRP(2);
	FMC_Bank5_6->SDTR[1] = TMRD(2) | TXSR(6) | TRAS(4) | TWR(2) | TRCD(2);
	//	FMC_Bank5_6->SDTR[0] = TRC(7)  | TRP(4);
	//	FMC_Bank5_6->SDTR[1] = TMRD(3) | TXSR(7) | TRAS(6) | TWR(3) | TRCD(4);

	// Initialization step 3
	while (FMC_Bank5_6->SDSR & FMC_SDSR_BUSY)
		;
	//PALL command (Pre-charge all banks)
	FMC_Bank5_6->SDCMR = 1 | FMC_SDCMR_CTB2 | (1 << 5);

	// Initialization step 4
	delay();
	delay();

	// Initialization step 5
	while (FMC_Bank5_6->SDSR & FMC_SDSR_BUSY)
		;
	// 2 = PALL (All Bank Precharge) command
	// SDRAM bank 2
	// 1<<5 = 2 Auto-refresh cycles
	FMC_Bank5_6->SDCMR = 2 | FMC_SDCMR_CTB2 | (1 << 5);

	// Initialization step 6
	while (FMC_Bank5_6->SDSR & FMC_SDSR_BUSY)
		;
	// 3 = Auto-refresh command
	// SDRAM bank 2
	// 4<<5 = 5 Auto-refresh cycles
	FMC_Bank5_6->SDCMR = 3 | FMC_SDCMR_CTB2 | (4 << 5);

	// Initialization step 7
	while (FMC_Bank5_6->SDSR & FMC_SDSR_BUSY)
		;
	// 4 = Load Mode Register
	// SDRAM bank 2
	// 1<<5 = 2 Auto-refresh cycles
	// Mode Register = 0x231: burst length 2, burst type sequential, CAS latency 3 clocks, Write burst mode single bit, normal operation mode
	// Mode Register = 0x030: burst length 1, burst type sequential, CAS latency 3 clocks, Write burst mode = single location access, normal operation mode
	FMC_Bank5_6->SDCMR = 4 | FMC_SDCMR_CTB2 | (1 << 5) | (0x231 << 9);

	// Initialization step 8
	while (FMC_Bank5_6->SDSR & FMC_SDSR_BUSY)
		;

	// refresh rate in number of SDCLK clock cycles between the refresh cycles
	// 683 = 7.6uS x 90Mhz
	// 7.6uS x 8196 rows = 62ms refresh rate
	FMC_Bank5_6->SDRTR |= (663 << 1);

	while (FMC_Bank5_6->SDSR & FMC_SDSR_BUSY)
		;

	// Clear SDRAM
	//for(ptr = SDRAM_BASE; ptr < (SDRAM_BASE + SDRAM_SIZE - 1); ptr += 4)
	//	*((uint32_t *)ptr) = 0xFFFFFFFF;
}
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

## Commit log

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2016-11-17 fixed pitch, mem loaded with triangle, oddly no glitching??
    [pitch-pot-cv.csv]
2016-11-22 Resampling happens smoothly, need to check for bugs. Could also be optimized when playing back at fast rates
    [main.c]
2016-12-15 Not working. Tries to read wav files, but goofs up the filesystem. Can't get it to work again by formatting.
    [main.c]
2016-12-18 Plays WAV files from an SD CARD that was formatted in FAT16 by an osx computer. Doesn't deal with stereo files or sample rates but it can load a file by name!
    [main.c]
2016-12-22 Detects number of channels in a sample and plays it Mono, Stereo Left, Stereo Right, Stereo Sum, depending on the stereo-mode switch setting. Only works with 16-bit wav files at this point. Added tri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
    [dig_pins.h, main.c]
2016-12-30 Files play better, less loading time. Using sdio driver from original sampler (p3). Using POLLING rather than DMA mode for sdio. Added bank LEDs, circular buffer for play_buff (not et implemented for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
    [dig_pins.c]
2017-01-03 REverses well, can't change direction live. The length param works better but still jumps around 50%
    [params.c]
2017-01-04 Can Reverse on the fly now, had to add ->seam to circular buffer. Doesn't use the LENGTH parameter now, but we can fix that in the next commit. Auto-reads the root directory and loads all .wav and .W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
    [params.c]
2017-01-06 Made LENGTH not fluctuate so much by using old_i_smoothed value instead of smoothed. More work on making the length work with reversing back and forth. Now it stops where you started if you play and 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
    [params.c]
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2017-01-10 Added button length press (long, short, medium) Holding down play button enables looping (button rgb not working for chan 2) Holding down REC enables monitoring of record (disabled by pressing play) 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
    [buttons.h, main.c, params.c]
2017-01-11 Added calcs/ directory and voltoct project which calculates the volt per octave response of the pitch jacks. Then changed the exp_1voct.h file to voltoct.h and fixed volt/oct response. Works well now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
    [main.c, params.c]
2017-01-12 Fixed bad diff_wrap routine and just using CB_distance now. Created -SAVE banks that cannot be changed by recording. Increased LENGTH time a bit, still needs work Changed response of LENGTH and START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
    [params.c]
2017-01-13 Updated to work with new faceplate (Swapped bank/play, only 10 samples per bank) Fixed lots of little bugs: stereo link could make it toggle playing or reverse, changing banks could mess up the sampl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
    [dig_pins.h, main.c, params.c]
2017-01-13 limit length param from being 0 Fixed looping with playing_perc, plays about the same sample position as forward. Hacked it, really should do the math and do it right
    [params.c]
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2017-01-15 Play button light flashes red if sample slot is empty, white if it's filled Recording only can happen if Enabled by holding down REC button for a second or two Separated LED Palette from max rec bank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
    [params.c]
2017-01-15 Fixed that last bug, it loads the right sample in assign mode when changing samples
2017-02-03 Starting to make playback happen from SDRAM if possible. It now reads into the circular buffer whenever playing, until the buffer is full or the entire sample is read, whichever happens first. Then i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
    [main.c, params.c]
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2017-02-28 Added Edit button (replaced Stereo switch). Assignment mode is now less modal, assign/edit params change while Edit button is held down only. Added ability to change Gain of a sample in edit mode, an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
    [buttons.h, dig_pins.c, dig_pins.h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]
2017-03-16 Fixed bug with holding down play button to stop looping makes it restart. Made trim_start have a fine feature that works better (static offset, not a percentage) Worked on cache, (formerly known as m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
    [params.c]
2017-03-17 Cleaned up toggle_reverse, toggle_play, read_storage_to_buffer, and play_audio_from_buffer so that it caches well. Added a fall-back fix for wav files with a longer length set by the 'data' chunk tha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
    Removed CircularBuffer fields seam, filled, stop_pt (not being used)
    Moved process_audio_block_codec into its own file
    [main.c]
2017-03-18 Removed the fadedown for polarity changing. Can't remember why I put it in there! It was causing problems when firing a trigger into REV and PLAY at the same time, PLAY detects it first and this fade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
    Made toggle_reverse work better in this use case (patch End Out into both PLAY and REV)
2017-03-25 Edit mode works! And fixed some weirdness with out-of-bounds
    [dig_pins.c, dig_pins.h, main.c]
2017-03-29 Progress at buffer overrun errors. Still makes crazy noise sometimes
    [dig_pins.c, dig_pins.h, params.c]
2017-03-30 Insured DMA mode was set up for SDIO. Changed DMA NVIC SDIO priority to 0/0. Learned that RXOVER error occurs often! so that's why it's disabled in DMA Read MultiBlocksFIXED. Hmm... Disabled SD detec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
2017-04-01 Clicky is gone??? Put read_storage_buffer into an interrupt with a fairly high priority so it won't get interrupted. Perhaps that was causing an issue... hmm... might be onto something. For now, with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
    Restored active buffer size (64 blocks) but still are not reading the cache_left to determine if we should read a block from the sdcard (that is, we don't need to fill the cache, just keep the buffer full).
    [main.c]
2017-04-13 Made trim_size nudged or set by fine or coarse (but not both). Made play trig jack always start the sample (instead of toggle it). Allowed sample to re-start if current play_state is PREBUFF or FADEU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
    [calibration.c, main.c, params.c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]
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2017-04-15 removed clip lights from showing error, fixed bug where play trig2 didnt work
    [main.c, params.c]
2017-05-05 Works with big (7mm) LEDs that are swapped B and G. Also with frosted buttons which need more brightness. Altered the colors a bit (more pinkish). Gain goes to 5.1. In debug mode, most timers should 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
    [main.c, params.c, pca9685_driver.c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]
2017-05-06 Stereo Link working (not selectable). Hear a noise when recording, need to investigate
    [params.c]
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2017-05-16 Trying to make SD card DMA use 8-bit blocks in memory, but still getting noise when playing two channels sometimes
2017-05-17 Activated bootloader and bootloader entry from main(). Fixed a bug with channel 2 not restarting play when in loop mode Starts on first bank after 2 (blue or later)
    [buttons.h, main.c]
2017-05-23 Reduced clutter in audio_sdram file. Made FIL type's buf[] element align to 4-byte words, this fixes misalignment in f_read on the first partial sector only. Changed resample_read24 so fractional_pos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
2017-05-25 Enchanced pre-buffering based on blockAlign and file sample rate, but still needs work. Fixed bug where rates other than 44.1kHz would play at wrong pitch.
2017-05-25 Enabled Clock Divider Bypass in SDIO setup, which runs the SDIO clock at 48MHz instead of 24MHz, for better thouroughput. Turned on Hardware Flow Control in the SDIO setup, which seems to avoid some 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
    [calibration.c]
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2017-06-01 Fixed LENGTH not going to 100%
    [params.c]
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2017-06-03 Edit mode fixes: stereo, gain, scrub entry
    Length/start pots don't wander as much to push you into scrub mode unintentionally. Stereo Mode is preserved when Reverting. Gain goes from 0.1 to 1.0 at 50%, then to 5.0 at 100%
    [params.c]
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2017-06-10 Can Hot-swap the SDCARD
    and force a reload of index by long-pressing Edit+Rev2
    [main.c]
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2017-06-13 LOAD
    sts_filesystem loading intermediate commit
    things that work
    empty lines can be added
    changing text in sample info or play data
    spaces in file name
    empty filenames are skipped until a file is found. Moves on to next bank section otherwise
    things that don't work
    only one file read per bank
    ----- headers cannot be changed
    path: cannot be changed
    removing one of the numbers in sample info
    doesn't handle spaces in path
    ideas
    use character to recognize begining of header --- to avoid str_cmp
    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
2017-06-13 Better guess at where to put recorded files
    Picks the folder of the sample in REC bank, or if that doesn't exist it picks the folder of another sample in the REC bank. If that fails, it uses the default bank folder
2017-06-13 Moved typedef Sample into sample_file.h
    And fixed some #includes
    [main.c]
2017-06-13 index write and load functions moved to index specific .c and .h files: sts_fs_index.c and sts_fs_index.h. Both functions are under developement. List of latest bugfixes and found bugs.
    WRITE
    - does not write content for empty sample name(s)
    FixMe:
    Sample info repeated for some files. One mono, the other stereo
    LOAD
    - handles spaces in file name(s)
    - handle spaces in file path(s)
    - handles random content before play info ( does not read sample info or whatever replaces it)
    - empty lines are ignored
    - text in play data is igonred and can be changed without affecting function. Just as long as the dashes are kept
    - empty filenames are skipped until a file is found. Moves on to next bank sec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
2017-06-15 PLay button's "dim" status stays updated
    Even when you change banks. Doesn't flash brightly when changing banks, only with Sample CV or knob
    [params.c]
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2017-06-16 Select a bank by holding button and turning Sample knobs
    Not fully tested, but seems to work OK. Added a new file to handle generic button/knob combo motions (will expand this file)
    Also fixed a bug with an infinite loop if no banks were found on boot.
    And cleaned up an error flag if you hit reverse before ever loading a sample.
    [params.c]
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2017-06-17 Bank selection works well, except....
    it lets you pick an empty bank.
    Besides that, it seems to work. Hovers over banks and sets the actual parameter when you release the button. Doesn't change the sample being played on either channel.
    Have not tested holding down both bank buttons at the same time and turning the Sample knobs...
    [params.c]
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2017-06-19 Fixed bug where you could select an empty bank
    Also fixed where it would go to white bank if you turn sample 2 too far.
    Now it blinks the bank button when you change to a new bank
    [params.c]
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2017-06-23 Edit mode -> Next File knows the default bank now
    By creating a bank path index array. However, we still have a problem if the first sample in the bank points to a file in the blue folder, but the rest of the files point to the pink folder, then the next time you boot up, going into edit mode for any sample in that bank will start looking from the blue folder (but should be pink.. probably?)
    [params.c]
2017-07-02 Fixed out-of-memory hardfault when recording, and made it more efficient
    Also corrected use of codec_dac_calibration_dcoffset
    [calibration.c]
2017-07-04 Auto calibrates and does RAM test on first boot
    Pitch pot detent can be calibrated, with LED feedback from play buttons.
    Added major/minor firmware version numbering.
    Swapped Pink and White banks for first and last (white is brighter, so better to boot on)
    Also made all fault handlers jump to application start
    [calibration.c, main.c, params.c]
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2017-07-05 Bug hunting for lock-up after recording
    Added more f_sync to write_sample_index(), and started using str_split instead of str_rstr.
    The thing that seemed to fix it is making the sample index be rewritten in the main loop by a flag set by wav_record
    [main.c]
2017-07-06 Animations for succes/fail on rewrite index
    [main.c]
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2017-07-06 Can browse unassigned samples forward
    Starts with folder of current sample, then does all other folders.
    Bug: sometimes won't load a sample, seems inconsistant upon restarts???
    [params.c]
2017-07-07 Assignment mode (seems to) work, forward by sample and backwards by bank
    Goes between unassigned and assigned samples without crashing.
    Both forward and backwards assignment motions use the same wrapper, which is called by setting a flag, and the main loop checks for the flag.
    Realized that all access to the SD card must be at the same interrupt level, or else we will get an error when, for example, trying to scan the card for unassigned files at the same time a file is being played back. For now, all functions that access the sd card must be in the main loop.
    Also tried setting _USE_LFN in ffconf.h to 2, which uses the stack for ff's buffers... might help some weird bugs we've been having?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
    [main.c]
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2017-07-08 Button press cleanup
    Save/Copy are short presses
    SkipProcessButtons works with Edit button now
    Bank Revert presses moved to multi-button-press section.
    Got Bank Reverts working, including visual feedback.
    [calibration.c, main.c]
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2017-07-11 Can drag and drop a folder of wavs into root, and it will load them.
    After loading sampleindex normally, it looks for new folders:
    -Folders with color names get put into that color bank (if the bank is already used, then it "bumps" them down to a higher blink number).
    -Folders with non-color names get loaded into the first empty bank
    -Added a lot of new functions, including 'copy_bank' and 'find_filename_in_bank'
    -load_bank_from_disk() now is given a sample array, not a bank number
    -Fixed str_startswith(), it would return a false 1 if len(string)<len(prefix)
    -ToDo: write load_missing_files(), which tries to fill vacant slots in a bank
    -ToDo: Test re-loading one bank (Edit+Rev2+BankX)... seem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
    [main.c]
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2017-07-11 bugfix: added system timer play delay on channel 2
    [params.c]
2017-07-12 RecBank button + RecSample knob sets the blink value of rec bank
    Tapping the RecBank button cycles through the color value only
    Also, holding down RecBank + a play Bank button for a short press will set the play bank to the Rec bank value
    -Temp fix: Removed rewriting index after recording (this will be disabled when FindMissingFiles branch is merged back anyways)
    [params.c]
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2017-07-13 Pitch slew fix: WIP. Timings are off...
    [calibration.c, params.c]
2017-07-13 Pitch slew when used with sequencer mostly fixed.
    PITCH adc values are processes separately in a regularly run routine.
    Switched PITCH to an arithmetic LPF, which reduces slew
    A structure is set up for delaying the cvadc_buffer values for pitch, but it's currently set to size=1 (no delay)
    When receiving a play trigger, it fades down the audio, and latches the cv adc value for a period, and inserts a delay until play is restarted. This delay is set to be enough for the LPF to stablize
    ToDo: If LOOP is on when using a CV/Gate sequencer, we get bad artifacts. We probably need to disable re-triggering when the playtrig delay is in effect.
    ToDo: Repeat this for other CV, especially start_pos
    [params.c]
2017-07-13 CV/Gate sequencer works better in LOOP mode
    But if LOOPing and triggering and LENGTH is set to PERC, still has a little glitch
    [params.c]
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2017-07-14 All CV jacks now use a FIR LPF
    Variable size for each, set in params.c
    Works for sequenceing start pos (except for file-reloading latency, which may be fixable?)
    [params.c]
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2017-07-14 non-envelope and envelope times change continuoulsy when turning the lenght knob for any file size. A plateau was added at the end of the lenght knob course to prevent EOF from being unreachable due 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
    [params.c]
2017-07-14 Fixed LED Palette's include method, so we can use palette names
    Should not change any performance
    [params.c]
2017-07-14 Minor tweak to length response
    Made it slightly faster at min knob setting, and removed the envelope skipping code in PLAYING_PERC block (sampler.c). Also made PLAYING_PERC loop with less silence
    [params.c]
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2017-07-14 Added tracking compensation (hard-set in code)
    Also fixed warble due to pitchpot using wrong value
    [calibration.c, main.c, params.c]
2017-07-14 Bug where all lights went out when holding SHORT_PRESS Edit+Rev2
    Now, Edit+Rev1 Medium hold goes back a bank, continuing to hold goes back more banks at a faster repeat rate than the initial delay
    [buttons.h]
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2017-07-15 Can swap between classic (slow) ADC and less-tested (fast) ADC
    Set X_FAST_ADC to 1 or 0 in globals.h
    This merges features of dev_master and SlewTime_Tweaks, so we can have one branch again
    [adc.c, params.c]
2017-07-17 Fixed bug where PLAYING_PERC over-played the cache, and adjusted pot LPF
    We had only been checking the sample_file_endpos when PLAYING, not when PLAYING_PERC. So with length=49%, we could often play past the end of the cache
    Also adjusted the LPF values for the knobs (Sample was warbling)
    [params.c]
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2017-07-19 index file is backed up at startup, before any changes are made to it. This is different from the index-bak which is used to revert bank(s). The later has file existence and bounds checks applied to 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
    [main.c]
2017-07-19 Fixed REV+PLAY bug (Joseph's bug).
    Stopped jumping application start on HardFault.
    Fixed math error in toggle_reverse
    Made timing between Play and Rev triggers dependant on sys_tmr, not cache position
    Added range checking for map_cache_to_buffer
    Added (commented out in resample.c:get_16b_sample_*()) range checking for reading samples from sdram... Todo: test if timing suffers when uncommenting these lines
    [main.c]
2017-07-19 Made shorthand for SDRAM_IS_BUSY
    Should compile exactly the same
    [sdram_driver.c]
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2017-07-21 Fixed issue where Sample2 CV would bleed onto Pitch1 CV
    Also, Pitch 1 would bleed to Pitch 2. Made ADC sample time longer for sample2, pitch1, and pitch2
    [adc.c]
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2017-07-25 Fault handlers reset NVIC
    [main.c]
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2017-07-26 Looping works well at fast lengths, and reverses corretcly
    Plays the same data fwd/back even in very small loops. Consistant period when reversing. Need to test more, but passed initial tests
    [dig_pins.c, dig_pins.h]
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2017-07-26 Channel 2 knobs latch when in Edit Mode
    Also fixed bug with the play_buff[]->in starting at a different place than ->out, when filling the cache and playing reverse (it was setting ->in back right after CB_init() and again after loading a block from sd card)
    [params.c]
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2017-07-26 Fixed bug where CV into Sample CV would not be read during button combo
    Bank1+Sample2 would disable Sample2 CV, and vice-versa
    [params.c]
2017-07-27 Volume control for channels
    Hold Rev1 and turn StartPos1 for channel 1, or Rev2+Start2 for chan 2.
    Volume updates when knob crosses last volume value (initial value is 100%).
    On releasing, StartPos does not change until knob is wiggled.
    Does not reverse when Rev button is released if knob was wiggled.
    CV seems to work at all times, adding to the current pot value or the latched value.
    Works with latching of Startpos2 during Edit mode (though latch value is not shared between modes)
    Should undergo more testing, but seems like it works
    [params.c]
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2017-07-27 Fixed Bank button not responding after button-knob combo
    [params.c]
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2017-08-01 Can turn on/off REC_24BITS state in System Mode
    Saves and restores state using settings.txt file
    Added Edit+Save and Edit+Revert to System Mode for save+exitting or reverting
    [buttons.h]
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2017-08-23 Less filtering on PitchCV and less trig delay, Fixed antihysterisis bug
    If adc_val swings so fast it jumps more than one detent range, it now accepts the new raw value's detent
    [params.c]
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2017-09-08 Added Quantized mode to System Mode
    New calibration setting: detune. (need to test)
    Re-did voltoct.h curve to match better real-world tests (408 ADC/Octave)
    Made Pitch CV bracket smaller (need to test for noise)
    Reduced Pitch CV plateau (need to make pitch CV jack calibration easier, or adjustable)
    Fixed tracking compensation function, so it rounds.
    [pitch-pot-cv.csv]
2017-09-08 Removed detune system setting, added semi-tone range for pitch pot
    Edit+Rec+RecBank for 2 seconds resets tracking_comp to 1.0
    Upgrading from 1.0 or 1.1 to 1.2 will reset tracking_comp to 1.0 (need to test)
    Quantize on/off is saved in settings file
    [pitch-pot-cv.csv]
2017-09-08 Clean up Quantize mode
    Med press is requred to enter system mode
    Fixed track moving pot was too long
    Changed color of Bank button in Sys Mode for Quantize on (red->blue)
    Changed button to view fw version in Sys Mode to Edit button
    Fixed quantize ch 2 settings file bug
    [params.c]
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2017-10-13 Adjustable trig delay time, is saved and different ranges for PCB v1/1.1
    Edit + RecSample sets the trig delay (button-knob-combo)
    Is saved automatically in settings.txt
    Removed play load triaging
    Fixed bug with sample_file_curpos not being file-specific
    Also--made Edit+Save save the user settings as well
    [main.c, params.c]
2017-10-13 v1.4, New Trig Delay values
    Better LED animation when changing trig delay
    Resets tracking comp setting when upgrading to v1.2 and later
    [params.c]
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2017-10-17 Many tweaks to timing and length: especially short samples
    Added enevlope on/off shortcuts with medium press Rev1 while Length is at 0 or 100
    [params.c]
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2017-10-20 Fixed bug in stop_pos calculation (appeared in 1.4),
    Also Env on/off would toggle during Volume combo.
    [params.c]
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2017-10-21 Doubled size of Pitch CV FIR filter (fixes warble)
    [params.c]
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2020-10-20 Calibrate mode not cleared after HW Test
    Fixed some float/double warnings
    [params.c]
2020-10-20 HW test halts if fails
    [main.c]
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2022-02-02 Fixed potential infinite loop when searching for a missing file replacement
    [main.c]
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2022-02-02 Fixed race condition with re-triggering a sample once buffer is full
    [params.c]
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2022-02-03 Fix missing includes from merge
    [main.c]
2022-02-03 Missing includes from merge
    [main.c]
2022-02-03 Renamed functions didn't get merged into hardware tests
    [main.c]
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2022-02-03 Moved ARM exception handlers to own file (and using DEBUG_ENABLE)
    Resets system if Debug is not enabled, otherwise loops forever
    [main.c]
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2022-02-04 Fixed button knob combo not updating
    [params.c]
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2022-02-07 Fixed LED display when changing Fade Time
    [params.c]
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2022-03-08 Fix rec sample rate not getting a sane default if missing from settings file
    [params.c]
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2022-06-28 Button combo to reload SD Card. Shorter System Mode button press
    [buttons.h, main.c]
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2022-10-04 Fix clicks when triggering over a sample that's playing
    The problem arises when the sample is still loud and a new trigger is received.
    When the new trigger is received, it immediately goes to FADEDOWN mode, while waiting for the trigger delay period. However, now that the fade-down time can be as long as 50ms, the sample might still be fading down
    when the trigger delay period ends.
    The fix is that after trigger delay, do a RETRIG_FADEDOWN to bring audio to 0 before playing.
    This adds 0.333ms of latency when triggering over already playing audio
    [params.c]
2022-10-04 Fix codec not recording at higher sample rates (wrong playback pitch)
    Was an initialization order issue. We have to read global_params before starting codec, because we need the record_sample_rate parameter in order to know what sample rate to run the codec.
    This fixes the issue where playing a sample recorded on the computer would play at the wrong pitch.
    The codec was always booting at 44.1kHz, but it was doing resampling based on the assumption the codec was running at `global_params.record_sample_rate`. So if you switched to 96kHz, the codec would too, and all would be OK. But when you restarted, the codec would be at 44.1k but the module would resample as if it was at 96kHz.
    [main.c]
2022-10-04 Seem to be missing a reset of LatchVoltOctCV?
    [params.c]
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2022-10-14 Fix Fade time (edit+length1) being updated immediately when Edit pressed
    [params.c]
2022-10-14 Fixed Start Pos not going back to 0
    [params.c]
